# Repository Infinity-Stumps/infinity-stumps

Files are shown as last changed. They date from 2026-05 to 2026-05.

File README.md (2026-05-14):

# Infinity Stumps

**DRS for the rest of us.** Hawk-Eye-class ball tracking and LBW prediction
for cricket, at roughly 1/30th the cost — running on a consumer phone.


&nbsp;Apache-2.0 / CERN-OHL-S / CC-BY-4.0

---

Eight ultra-wideband (UWB) anchors around a cricket pitch, a tag inside the
ball, and a phone that does all the maths. It tracks the ball in 3D, predicts
trajectories, and renders DRS-style LBW verdicts — for the 99% of cricket
played in clubs, schools, academies, and back gardens that has never had
access to ball-tracking analytics.

The whole system is **open by design** — public from day one as dated,
detailed prior art so the techniques can't be locked up by anyone else.
See [`docs/about.md`](docs/about.md) for the what, why, and the open-source
posture.

## Headline results

Phase 0 simulation, n=30 deliveries at 100 Hz with a realistic occlusion
model (skeleton batter + Law-41 bowler), EKF + RTS smoother pipeline:

| Metric | Result | iBall (NSDI '17) | |
|---|--:|--:|--|
| Lateral median error at the stump line | **9.1 mm** | 99 mm | 11× better |
| 3D median error at the stump line | **28.0 mm** | 220 mm | 7.9× better |
| LBW verdict accuracy (exact match) | **96.7%** | — | 29/30 |
| False positives (wrong OUT) | **0** | — | across all 30 |

Full breakdown in [`docs/status-2026-05-13.md`](docs/status-2026-05-13.md).

## Repository layout

This is a monorepo, one directory per discipline:

| Directory | What's in it | Status |
|---|---|---|
| [`simulation/`](simulation/) | The Python estimation + LBW pipeline — physics EKF, RTS smoother, verdict logic, and the simulation harnesses that validate them. | Phase 0 complete |
| [`firmware/`](firmware/) | Anchor and ball-tag firmware for the Qorvo DWM3001C (C / nRF Connect SDK). | Not started |
| [`hardware/`](hardware/) | KiCad PCB projects and enclosure design. | Not started |
| [`app/`](app/) | The mobile app — iOS first; runs the full pipeline on-device. | Not started |
| [`docs/`](docs/) | System-level architecture, BOM, prior-art strategy, test plans. | Living |

Each directory has its own README with the detail.

## How the system works

```
  ball tag ──UWB DS-TWR @ 100 Hz──▶ 8 anchors ──▶ hub stump ──BLE──▶ phone
                                                                      │
                          per-anchor ranges ──▶ physics EKF ──────────┤
                                               + RTS smoother         │
                                               + LBW verdict          ▼
                                                          trajectory + verdict
```

- **Hardware** — 8 Qorvo DWM3001C anchors (4 stump-top, 4 ground-level), one
  designated the hub stump; a DWM3001C + impact accelerometer in the ball.
- **Estimation** — a 9-state physics EKF over (position, velocity, spin) with
  a drag + Magnus + gravity ODE, plus an RTS backward smoother for
  replay-quality precision. Runs on the phone.
- **LBW** — forward-extrapolates past the pad to the stump line, propagates the
  EKF covariance into a 95% confidence ellipse, classifies it against the
  stump rectangle as HITTING / MISSING / UMPIRE'S CALL.

## Getting started

The Phase 0 work lives in [`simulation/`](simulation/) — see its README:

```bash
cd simulation
make install
make test
python sims/sim_lbw.py
```

## Documentation

- [`docs/about.md`](docs/about.md) — what this is, the open-source posture, the prior-art strategy.
- [`docs/architecture.md`](docs/architecture.md) — full system architecture.
- [`docs/bom.md`](docs/bom.md) — active bill of materials (Qorvo DWM3001C platform).
- [`docs/prior-art.md`](docs/prior-art.md) — iBall (NSDI '17) analysis and borrowed techniques.
- [`docs/status-2026-05-13.md`](docs/status-2026-05-13.md) — current results in detail.
- [`docs/phase1-2-test-plan.md`](docs/phase1-2-test-plan.md) — hardware bring-up plan.
- `CLAUDE.md` — the running decision log. `CONTRIBUTING.md` — how to work on the project.

## Licence

Three licences by file type:

- **Software** (`simulation/`, `firmware/`, `app/`) — Apache-2.0 ([`LICENSE`](LICENSE))
- **Hardware designs** (`hardware/`) — CERN-OHL-S v2 ([`LICENSE-hardware`](LICENSE-hardware))
- **Documentation** (`docs/`, READMEs) — CC-BY-4.0 ([`LICENSE-docs`](LICENSE-docs))

## Acknowledgements

Built on **iBall** (Gowda et al., *Bringing IoT to Sports Analytics*, NSDI '17),
which established UWB ranging + physics-fit + LBW extrapolation for a cricket
ball as public prior art. This project productises that idea with modern
silicon, an 8-anchor topology, and outdoor validation.

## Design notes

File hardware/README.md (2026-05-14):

# Hardware

PCB and mechanical design for the Infinity Stumps anchors and ball tag.
Electronics built around the **Qorvo DWM3001C** module — see
`docs/bom.md` for the full bill of materials and `docs/architecture.md`
for the system design.

## Layout

| Directory | Contents |
|---|---|
| `anchor-board/` | The anchor PCB — **one design serves all eight anchor positions**. Every board is built identically (flash + load switch populated); the hub role (A7) is firmware-only and any board is hub-promotable by reflashing. Tall-and-thin to fit inside the stump. KiCad project. See its `README.md` for the full design spec. |
| `pai-board/` | The PAI (ground-level) anchor — **not an independent design**, just a one-component fork of `anchor-board/`: USB-C receptacle swapped for a magnetic charging connector, in an IP67 sealed cylinder. Same board family, same Gerbers minus the USB-C cluster. |
| `ball-tag/` | The in-ball tag — a custom 4-layer flex PCB shaped to the ball interior, carrying the DWM3001C + ADXL372 impact accelerometer + small LiPo. |
| `mechanical/` | Enclosure design — stump-top caps, PAI housings, ball shell. STL + STEP. |

Each board is its own KiCad project (schematic + layout + Gerbers).
Manufacturing outputs are committed alongside the source.

## Status

Not started. PCB design follows firmware bring-up on the DWM3001CDK
dev kits.

## Licence

CERN-OHL-S v2 — strongly reciprocal (see `LICENSE-hardware` at the repo
root). Mechanical design files (STL/STEP) are CC-BY-4.0 per the project
licensing in `docs/about.md`.

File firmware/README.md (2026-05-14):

# Firmware

Embedded firmware for the Infinity Stumps UWB nodes. All nodes are built
on the **Qorvo DWM3001C** module (DW3110 UWB transceiver + Nordic
nRF52833 BLE/MCU, with an on-module 3-axis accelerometer and 32.768 kHz
crystal).

Toolchain: **Nordic nRF Connect SDK** (Zephyr-based). The DWM3001CDK dev
kit *is* the production module, so bring-up firmware transfers directly
to production hardware.

## Layout

| Directory | Role |
|---|---|
| `anchor/` | Anchor firmware. One image with a build-time role flag — a **dumb anchor** ranges and relays; a **hub anchor** additionally acts as UWB sync master, range aggregator, BLE gateway to the phone, and disconnect-cache recorder. 7 dumb + 1 hub per pitch. |
| `ball-tag/` | Ball-tag firmware. Drives the UWB ranging exchange and reads the impact accelerometer (ADXL372) for bounce/pad/bat event timing. |
| `common/` | Shared code — UWB ranging (broadcast DS-TWR @ 100 Hz), the fixed-schedule TDMA data layer on the 802.15.4z PHY, power management, BLE service definitions. |

## Status

Not started. Phase 1+2 (hardware bring-up) begins when the DWM3001CDK
boards arrive — see `docs/phase1-2-test-plan.md` and `docs/architecture.md`.

## Licence

Apache-2.0 (see `LICENSE` at the repo root).

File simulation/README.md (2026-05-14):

# Infinity Stumps — Simulation

The Python estimation and LBW-prediction pipeline, plus the simulation
harnesses that validate it. This is the **Phase 0** work: the algorithm
architecture proven end-to-end in simulation before any hardware is built.

It is also the reference spec the firmware and the mobile app are ported
from — see the other top-level directories and the repo-root
[`README.md`](../README.md) for the whole-system picture.

## Headline results

n=30 deliveries at 100 Hz with a realistic occlusion model (skeleton
batter + Law-41 bowler), EKF + RTS smoother pipeline:

| Metric | Result | iBall (NSDI '17) | |
|---|--:|--:|--|
| Lateral median error at the stump line | **9.1 mm** | 99 mm | 11× better |
| 3D median error at the stump line | **28.0 mm** | 220 mm | 7.9× better |
| Trajectory RMS (replay) | **47.3 mm** | — | |
| LBW verdict accuracy (exact match) | **96.7%** | — | 29/30 |
| False positives (wrong OUT) | **0** | — | across all 30 |

Full breakdown in [`../docs/status-2026-05-13.md`](../docs/status-2026-05-13.md).

## The pipeline

- **Physics EKF** — a 9-state Extended Kalman Filter over (position, velocity,
  spin), propagated with a drag + Magnus + gravity ODE and updated per UWB
  range measurement. Runs forward in real time for a live overlay.
- **RTS smoother** — a Rauch–Tung–Striebel backward pass that retrofits past
  estimates with later measurements for replay-quality precision.
- **LBW pipeline** — forward-extrapolates the ball past the pad to the stump
  line, propagates the EKF covariance into a 95% confidence ellipse, and
  classifies it against the stump rectangle as HITTING / MISSING / UMPIRE'S CALL.

## Layout

| Path | What's in it |
|---|---|
| `src/infinity_stumps/geometry.py` | Pitch geometry, anchor layouts, GDOP. |
| `src/infinity_stumps/physics.py` | Ball flight dynamics (drag + Magnus + gravity, bounce). |
| `src/infinity_stumps/solver.py` | Multilateration and physics-constrained trajectory fit. |
| `src/infinity_stumps/ekf.py` | The production estimator: trajectory EKF + RTS smoother. |
| `src/infinity_stumps/lbw.py` | LBW extrapolation, uncertainty ellipse, verdict logic. |
| `src/infinity_stumps/noise.py` | UWB ranging noise models (Gaussian + occlusion/NLOS). |
| `src/infinity_stumps/skeleton.py` | Anthropometric skeleton batter for the occlusion model. |
| `sims/` | Standalone simulation scripts — each writes a PNG to `outputs/`. |
| `tests/` | Per-module test suite (`pytest`). |
| `outputs/` | Committed simulation result figures. |

## Quickstart

Requires Python 3.10+. Run everything from this directory.

```bash
make install      # editable install with dev extras + pre-commit hooks
make test         # run the test suite
make check        # the full gate: lint + typecheck + test
make sims         # regenerate every figure in outputs/
```

`make help` lists every target. Without `make`:

```bash
pip install -e ".[dev]"
pytest
python sims/sim_lbw.py
```

## Simulations

Each script in `sims/` is self-contained and writes a figure to `outputs/`.

| Script | What it shows |
|---|---|
| `sim_ekf.py` | **EKF + RTS smoother** — the production estimator (current primary). |
| `sim_lbw.py` | **LBW prediction + verdict** — 96.7% exact-match accuracy. |
| `sim_realistic.py` | Batch-fit baseline under realistic occlusion (deprecated primary). |
| `sim_ml.py` | ML correction-layer exploration (concluded net-neutral). |
| `01_precision_map.py` | GDOP map across the pitch. |
| `02_anchor_comparison.py` | 8 vs 12 anchors (12 rejected — <2% gain). |
| `03_trajectory_recovery.py` | Clean-LOS physics fit. |
| `05_multipath_occlusion.py` | NLOS impact, no mitigations (the problem). |
| `05b_occlusion_mitigations.py` | Huber loss + NLOS detection (the fix). |
| `06_imu_fusion.py` | Complementary-filter IMU fusion (rejected — see `../docs/findings.md`). |
| `07_sync_budget.py` | TDoA noise floor (why the system uses TWR, not TDoA). |
| `11_ground_multipath.py` | Outdoor ground-reflection multipath. |

## Contributing

See [`../CONTRIBUTING.md`](../CONTRIBUTING.md). In short: `make check` must
pass, and the project values dated decisions and explicit reasoning.

## Licence

Apache-2.0 (see [`../LICENSE`](../LICENSE)).

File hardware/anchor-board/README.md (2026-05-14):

# Anchor Board

The stump-anchor PCB for Infinity Stumps. **One board design serves all
eight anchor positions** — the four stump-top anchors (A1, A2, A7, A8)
and, with only an enclosure + charge-connector change, the four in-ground
PAI anchors (A3–A6). The hub role (A7) is **firmware-only**: the same
fully-populated board, reflashed.

This document is the design specification — form factor, functional
blocks, the complete passive component list, pin allocation, layout
rules, and the dev-board → production-board conversion plan. It should be
read alongside `docs/bom.md` (costed BOM) and `docs/architecture.md`
(system design). KiCad project lives in this directory once started.

**Status:** specification. No schematic/layout yet.

---

## 1. Design philosophy: one board, dev first, production by subtraction

The board is designed as a **development board that converts into the
production board by subtraction only** — no re-layout, no re-spin.

This is cheap to do here because the **DWM3001C is a pre-certified
module**, not a bare chip: the nRF52833 MCU, the DW3110 UWB radio, the
UWB + BLE antennas, the 32.768 kHz LFXO crystal and a low-g accelerometer
are all *inside* the module. The board we are designing is therefore a
**carrier** — power, charging, storage, status I/O, and breakouts. There
is almost no RF layout risk (just a keepout under the module antenna), so
"dev = production + extra parts" is genuinely achievable.

**Mechanism:**

- **Single 4-layer PCB, single set of Gerbers, two assembly BOMs.**
- The production circuit lives in the board core.
- All dev-only conveniences (full SWD header, UART header, GPIO breakout,
  current-measurement shunt, LED-disable jumper) sit on a **V-scored
  break-off rail** along one long edge.
- For production: snap off the rail and mark the dev-only parts DNP. Same
  fab output, different pick-and-place file.

See §8 for the full conversion checklist.

### Hub vs dumb: populate flash on every board

**This design populates the 16 MB flash + load switch on every board.**
The cost is ~£1.20/board (~£8/pitch — noise against the ~£601 pitch
cost), and in return there is a **single assembly BOM** and **any board
is promotable to hub by reflashing**. No second variant to stock, build,
or track. The hub/dumb distinction is entirely firmware. `docs/bom.md`
is written to match — there is no separate hub SKU.

---

## 2. Form factor — tall and thin, fits inside the stump

The board drops vertically down inside a hollow cricket stump (≈38 mm
outer diameter, ≈30–34 mm internal bore). It occupies only the **upper
~145 mm** of the stump.

**Nominal envelope: 25 mm wide × ≈145 mm long, 4-layer, 1.6 mm.**

Width is set by the DWM3001C (19.13 mm wide) plus a ~3 mm routing rail
each side. Length is a vertical stack of functional zones:

```
   ┌─────────────┐  ← TOP of stump (z = 680 mm anchor reference point)
   │  ANTENNA    │  ~6 mm   Module sits fully on-board; this zone is an
   │  (keepout)  │          all-layer copper keepout under the DWM3001C
   │             │          antenna, per the Qorvo integration guide.
   ├─────────────┤
   │  DWM3001C   │  ~21 mm  Module body. Castellation pads both long
   │   MODULE    │          edges. Decoupling on the back side.
   ├─────────────┤
   │  POWER &    │  ~30 mm  LDO, charger, battery protection, SPI flash,
   │  SUPPORT    │          load switch, ESD array, RGB LED, button.
   ├─────────────┤
   │             │
   │   18650     │  ~77 mm  Keystone 1042 single-cell holder, PC-pin
   │   HOLDER    │          mount. Battery sits on top of the PCB; this
   │             │          zone carries no other components.
   │             │
   ├─────────────┤
   │  USB-C +    │  ~12 mm  USB-C receptacle on the long edge, port
   │  CHG INPUT  │          facing OUT the side of the stump.
   └─────────────┘  ← ≈145 mm below stump top — still ≈350 mm+ above
                      ground, so the side charge slot stays clear of
                      the buried portion of the stump.
═══ V-score ═══════  Break-off dev rail runs the full length on one
   [ dev rail   ]    long edge (see §7).
```

**Cross-section inside the stump:** PCB (25 mm × 1.6 mm) with the 18650
(≈18 mm dia) lying on top → ≈25 mm wide × ≈20 mm tall. Comfortably
inside a ≈30–34 mm bore. The 18650 holder must be retained against the
PCB with the BOM's cell clip — the board will see knocks and the ball's
impact shock through the stump.

**Orientation is fixed:** antenna end UP (it is the anchor's z = 680 mm
reference point), USB-C end DOWN. The PAI variant has no "up" constraint
and swaps the USB-C zone for a 2-pin magnetic charge connector.

---

## 3. Functional block diagram

```
                 USB-C VBUS ─► [TPD4S014] ─► [BQ24074] ─► VSYS ──┬──► [TLV75530] ──► 3V0 rail
                 (5 V in)       ESD/TVS       Li-ion charger      │     LDO            │
                                                  │              │                   ├─► DWM3001C  (2.5–3.6 V)
                 USB-C CC1/CC2 ─► 5k1 Rd ─► GND   │              │                   ├─► W25Q128 flash
                                                  ▼              │                   │   (via TPS22916 switch)
                                       [18650 cell] ◄─► [DW01A    │                   ├─► RGB LED
                                        3400 mAh        + 8205A]  │                   └─► (button pull-up)
                                                        protection│
                                                                  │
                          VBAT sense divider ──────────────────────┘──► nRF52833 ADC

   DWM3001C (module): nRF52833 MCU + DW3110 UWB + on-module antennas,
                      32.768 kHz LFXO, low-g accel — all internal.
        GPIO ─► SPI to W25Q128   │   GPIO ─► TPS22916 ON   │   GPIO ─► RGB LED ×3
        GPIO ◄─ power button     │   ADC  ◄─ VBAT sense    │   GPIO ◄─ BQ24074 /CHG, /PGOOD
        SWD / UART / spare GPIO ─► break-off dev rail
```

---

## 4. Functional blocks and their passives

This is the **complete passive list**, grouped by block. Values are the
design intent; finalise against each IC's datasheet app circuit during
schematic capture. Reference designators are indicative.

### 4.1 DWM3001C module

The module needs almost nothing external — its job is done internally.

| Ref | Part | Value | Purpose |
|---|---|---|---|
| C1, C2 | Capacitor 0402 | 100 nF | VDD pin decoupling, one per supply pin group, placed hard against the castellations |
| C3 | Capacitor 0805 | 10 µF | Bulk decoupling on the module 3V0 feed |
| R1 | Resistor 0402 | 10 kΩ | nRESET pull-up |
| C4 | Capacitor 0402 | 100 nF | nRESET RC debounce (to GND) |

Antenna region: **copper keepout on all layers** under and around the
module's antenna end, per the Qorvo DWM3001C integration guidelines. No
ground pour, no traces, no vias. The module sits **fully on the board**
(no overhang) — the keepout gives the RF clearance, and keeping the
module fully supported is the mechanically robust choice inside the cap,
where the board takes ball-impact shock through the stump.

### 4.2 USB-C input + ESD (production: stump anchors only)

Sink-only, no USB-PD, no data — power in at 5 V.

| Ref | Part | Value | Purpose |
|---|---|---|---|
| J1 | GCT USB4105-GF-A | — | USB-C receptacle, long-edge mount, port facing out |
| R2, R3 | Resistor 0402 | 5.1 kΩ | CC1 / CC2 pull-downs (Rd) — required for a source to detect the sink |
| C5 | Capacitor 0805 | 10 µF | VBUS bulk cap |
| C6 | Capacitor 0402 | 100 nF | VBUS HF decoupling |
| U2 | TI TPD2E2U06 | — | 2-channel low-cap (1.5 pF) TVS ESD array on the CC1 / CC2 lines |
| D2 | TVS diode, SMF5.0A class | — | VBUS ESD / surge clamp (~5 V standoff), VBUS → GND |
| R4 | Resistor 0402 | 1 MΩ | Shield-to-GND bleed (parallel with C7) |
| C7 | Capacitor 0402 | 4.7 nF | Shield-to-GND, chassis noise return |

> **ESD parts — changed from the original spec.** The first draft listed
> a single TI TPD4S014, but that is a USB *data-port* protector
> (D+/D−/ID clamps + a VBUS load switch) — wasted on this sink-only,
> power-only port. Replaced with the **TPD2E2U06** (TI's CC-line ESD
> array) plus a dedicated **VBUS TVS diode (D2)**.

> **PAI variant:** J1, R2, R3 and U2 are replaced by a 2-pin magnetic
> charge connector (Rosenberger) — the magnetic connector has no CC
> lines, so the CC pull-downs and the CC ESD array are not fitted. D2
> (VBUS TVS) stays; the magnetic connector still feeds VBUS. This is the
> only electrical difference between the stump and PAI boards.

### 4.3 Li-ion charger — TI BQ24074

| Ref | Part | Value | Purpose |
|---|---|---|---|
| U3 | TI BQ24074 | — | USB-input Li-ion CC/CV charger |
| C8 | Capacitor 0603 | 1 µF | IN pin input cap |
| C9 | Capacitor 0603 | 1 µF | OUT pin cap |
| C10 | Capacitor 0603 | 1 µF | BAT pin cap |
| R5 | Resistor 0402 | 909 Ω | ISET — fast-charge current ≈ 1.0 A (≈0.3C on a 3400 mAh cell; conservative for outdoor temps) |
| R6 | Resistor 0402 | TBD | TMR — safety-timer program resistor, sized for a ~10 h timer (generous margin over a ~0.3C charge); value from the BQ24074 datasheet timer equation at schematic capture |
| R7, R8 | Resistor 0402 | 10 kΩ + 10 kΩ | TS pin — equal divider holds TS at mid-rail, disabling temperature sensing in v1 (no pack thermistor). v2 may swap R8 for an NTC. |
| R9, R10 | Resistor 0402 | 10 kΩ | /CHG and /PGOOD open-drain pull-ups to 3V0, also sensed by MCU GPIO |
| R11, R12 | Resistor 0402 | strap | EN1 / EN2 mode straps — set input current limit (USB500 / ISET) |
| R24 | Resistor 0402 | TBD | ILIM — input-current-limit program resistor; value from the BQ24074 datasheet at schematic capture |
| R25 | Resistor 0402 | TBD | ITERM — charge-termination-current program resistor; value from the BQ24074 datasheet at schematic capture |

> **R24 / R25 added during schematic capture.** The BQ24074's ILIM
> (input current limit) and ITERM (termination current) pins each need a
> program resistor; the original §4.3 list omitted them. The refs
> continue past the §4 sequence (R15–R23 belong to §4.6–4.8).

### 4.4 Battery + protection — 18650 + DW01A/8205A

| Ref | Part | Value | Purpose |
|---|---|---|---|
| BT1 | Panasonic NCR18650B | 3400 mAh | Single Li-ion cell, in Keystone 1042 holder |
| U4 | DW01A | — | Protection controller (over-charge / over-discharge / over-current) |
| U5 | 8205A | — | Dual N-FET, protection switch (no passives of its own) |
| R13 | Resistor 0402 | 330 Ω | DW01A VCC series resistor |
| C11 | Capacitor 0402 | 100 nF | DW01A VCC–VSS decoupling |
| R14 | Resistor 0402 | 2 kΩ | DW01A current-sense input resistor |

### 4.5 3.0 V regulation — TI TLV75530

| Ref | Part | Value | Purpose |
|---|---|---|---|
| U6 | TI TLV75530PDQNR | 3.0 V | Low-IQ 500 mA LDO, battery → 3V0 system rail |
| C12 | Capacitor 0603 | 1 µF | VIN cap |
| C13 | Capacitor 0603 | 1 µF | VOUT cap |
| C14 | Capacitor 0805 | 10 µF | 3V0 rail bulk cap |
| FB1 | Ferrite bead 0603 | — | Optional: charger-OUT → LDO-IN, isolates charge ripple from the rail |

### 4.6 SPI flash + load switch — W25Q128 + TPS22916C

Populated on **every** board (see §1).

| Ref | Part | Value | Purpose |
|---|---|---|---|
| U7 | Winbond W25Q128JVSIQ | 16 MB | Disconnect-cache flash (hub firmware uses it; dumb firmware leaves it idle) |
| U8 | TI TPS22916C | — | Load switch — gates flash VCC in deep sleep (~1 µA saving) |
| C15 | Capacitor 0402 | 100 nF | W25Q128 VCC decoupling |
| C16 | Capacitor 0603 | 1 µF | TPS22916 output cap |
| R15 | Resistor 0402 | 10 kΩ | /CS pull-up (idle-high during MCU boot) |
| R16, R17 | Resistor 0402 | 10 kΩ | /WP and /HOLD pull-ups (single-SPI mode, tied inactive) |

> **C17 removed during schematic capture.** The original list specced a
> "TPS22916 CT" slew-rate cap, but the TPS22916 (4-pin WCSP — VIN / VOUT
> / GND / ON) has **no CT pin**; turn-on slew rate is fixed by the part
> variant (the "C" suffix = slow timing), not an external cap.

### 4.7 User I/O — RGB LED + power button

| Ref | Part | Value | Purpose |
|---|---|---|---|
| D1 | Würth 150141RV73100 | — | Common-anode RGB status LED, 0805 |
| R18 | Resistor 0402 | 1 kΩ | Red current limit (run dim — LED is a battery drain) |
| R19 | Resistor 0402 | 680 Ω | Green current limit |
| R20 | Resistor 0402 | 680 Ω | Blue current limit |
| SW1 | Alps SKHHALA010 | — | Side-mounted IP67 tactile power/mode button |
| R21 | Resistor 0402 | 10 kΩ | Button pull-up (or use nRF internal pull and DNP) |
| C18 | Capacitor 0402 | 100 nF | Button debounce |

> **Power-button behaviour: soft-wake, no hard latch.** The button is an
> MCU GPIO wake/mode source; "off" is nRF52833 deep sleep (System OFF
> ≈ a few µA; the power budget's conservative ~50 µA sleep figure
> already covers this). No load-switch latch on the 3V0 rail. Rationale:
> the anchor must always be able to wake on UWB, BLE or motion — a hard
> "dead until button" state breaks the hub-as-recorder behaviour and the
> 290-day runtime is already computed against deep sleep, not a true
> zero-draw off. Fewer parts, more robust.

### 4.8 Battery voltage sense

Needed for the `battery_pct` field in the hub's BLE Status characteristic.

| Ref | Part | Value | Purpose |
|---|---|---|---|
| R22, R23 | Resistor 0402 | 1 MΩ + 1 MΩ | High-impedance divider, VBAT → nRF ADC pin (≈2 µA drain — acceptable vs 50 µA sleep) |
| C19 | Capacitor 0402 | 100 nF | ADC anti-alias / sample-and-hold filter |

### 4.9 Rail-level / misc

| Ref | Part | Value | Purpose |
|---|---|---|---|
| TP1–TP6 | Test points | — | VBUS, VSYS, VBAT, 3V0, GND ×2 — keep on the production board, they cost nothing |
| C20 | Capacitor 0805 | 10 µF | Extra 3V0 bulk near the module if layout needs it |

**Passive count, production board:** ≈40 parts — caps, resistors, one
ferrite. All 0402/0603/0805, single reel-friendly family. This maps to
the BOM's "Bulk decoupling caps ×4 / Misc passives" lines, which should
be expanded to match this list (see §10).

---

## 5. Pin allocation (reconciled against the datasheet)

Finalised against the DWM3001C datasheet castellation map (Data Sheet
Rev F, §3). The schematic symbol and netlist now use the **real pin
numbers**; `tools/gen_dwm3001c_symbol.py` is the source of this table.

| Function | Module pin | nRF GPIO | Notes |
|---|---:|---|---|
| VDD | 12 | — | 3.0 V supply from the LDO |
| GND | 1, 11, 21, 38, 48 | — | All five module grounds tied to GND |
| nRESET | 47 | P0.18 | R1 pull-up; TC2030 pads + dev-rail header |
| SWDCLK | 2 | — | Dedicated SWD; TC2030 pads + dev-rail header |
| SWDIO | 3 | — | Dedicated SWD; TC2030 pads + dev-rail header |
| UART_TX | 27 | P1.09 | nRF log console → dev-rail header only |
| UART_RX | 28 | P1.00 | nRF log console → dev-rail header only |
| BTN | 13 | P0.12 | Power/mode button, wake source |
| CHG_STAT | 17 | P0.20 | BQ24074 /CHG (open-drain) |
| PGOOD | 16 | P0.21 | BQ24074 /PGOOD (open-drain) |
| VBAT_SENSE | 42 | P0.31 | SAADC AIN7 — via R22/R23 divider |
| SPI_SCK | 22 | P0.11 | W25Q128 flash |
| SPI_MOSI | 23 | P1.08 | W25Q128 flash |
| SPI_MISO | 24 | P0.06 | W25Q128 flash |
| SPI_CS | 25 | P1.01 | W25Q128 flash |
| FLASH_EN | 26 | P0.13 | TPS22916 ON pin |
| LED_R / LED_G / LED_B | 6 / 7 / 8 | P0.17 / P0.14 / P0.22 | RGB LED, common-anode (drive low = on) |
| GPIO1–4 | 29 / 32 / 33 / 34 | P1.05 / P0.15 / P0.28 / P0.19 | Spare, broken out to the dev rail |

Pins **4, 5** (P0.09/P0.10) default to NFC and are left unconnected.
Pins **14, 15** (P0.24/P1.04) are the **on-module accelerometer I²C** —
left unconnected so the carrier never drives them. The remaining
castellations (USB_N/P, the DW3110 GPIOs, spare P0.x) are typed
`no_connect` in the symbol — those pads float on this board by design.
There is no EN1/EN2 GPIO: the BQ24074 mode is hard-strapped (R11/R12),
which was always the plan — the earlier "EN1/EN2" pins were a
placeholder-symbol artefact, now gone.

The DW3110 UWB radio talks to the nRF52833 over an **on-module** SPI bus
— not exposed, not our concern.

---

## 6. Layer stack-up and layout rules

**4-layer, 1.6 mm:** `Signal / GND / PWR / Signal`.

1. **Antenna keepout** — the single hard RF rule. All-layer copper
   keepout under/around the DWM3001C antenna end, per Qorvo's
   integration guide. No pour, no trace, no via, no battery, no metal
   nearby. This protects the module's pre-certification.
2. **Module placement** — DWM3001C at the top edge, antenna outboard.
   Decoupling caps (C1–C3) on the *back* side directly behind the supply
   castellations.
3. **USB-C** — keep VBUS traces short and wide; TPD4S014 placed right at
   the connector, before anything else. CC pull-downs at the connector.
4. **Charge/power path** — BQ24074 → DW01A/8205A → TLV75530 in a compact
   cluster in the Power & Support zone. Keep the high-current battery
   loop (cell → 8205A → charger/load) tight; star-ground the analog
   return of the VBAT divider away from it.
5. **18650 zone** — no components, but route the cell + / − traces
   wide (charge current up to 1 A). The holder's PC pins anchor it
   mechanically; pair with the BOM cell clip.
6. **Thermal** — negligible. Worst case ≈8 mA average, ≈1 A only while
   charging; modest copper pour on the PWR layer around the charger is
   plenty. No concern in a sealed stump.
7. **Mechanical** — M2 mounting holes (BOM standoffs) at the corners of
   the rigid core; keep them out of the antenna keepout. The board takes
   ball-impact shock transmitted through the stump — no tall unsupported
   parts, secure the cell.

---

## 7. The break-off dev rail

A V-scored strip down one long edge, snapped off for production. Carries
**only** bring-up and validation aids:

| Dev-rail item | Why it is dev-only |
|---|---|
| 2×5 1.27 mm SWD/JTAG header | Production uses the Tag-Connect pads on the core board; the shrouded header is faster for daily flashing/debug |
| UART header (TX/RX/GND) | nRF RTT/console logging during bring-up |
| GPIO breakout (spare ×4–6 + I²C/SPI taps) | Probing, logic analyser, attaching test sensors |
| **3V0 current-shunt jumper** | A 2-pin header in series with the 3V0 rail. Pull the jumper, insert a µA meter — **this is how the 290-day / ~50 µA sleep budget gets validated.** Production: replace with a 0 Ω. |
| LED-disable jumper | LEDs wreck a sleep-current measurement; cut them cleanly during power profiling |
| Boot/mode strap pads | Recovery / forced-DFU during firmware bring-up |

The core board is **fully functional with the rail removed** — the
Tag-Connect pads, the 0 Ω in place of the shunt jumper, and the on-board
RGB LED cover everything production needs.

---

## 8. Dev → production conversion checklist

No re-layout. No re-spin. Same Gerbers. To go from dev to production:

1. **Snap off** the V-scored dev rail.
2. **Fit R_shunt = 0 Ω** in the current-shunt jumper position.
3. **Mark DNP:** dev-rail parts (already gone with the rail), the SWD
   shrouded header, UART header, GPIO breakout, mode-strap pads.
4. **Stuff the Tag-Connect TC2030 pads** (they are on the core board, not
   the rail).
5. Swap the **assembly/pick-and-place BOM** to the production variant.
   Fab output (Gerbers, drill, netlist) is **identical**.
6. PAI-board fork only: swap the USB-C cluster (J1/R2/R3) for the
   magnetic connector footprint — a one-component schematic change, same
   board family.

---

## 9. Decisions made and remaining open items

**Resolved in this design:**

- **Form factor** — ≈25×145 mm, tall-and-thin (§2). `docs/bom.md` updated
  to match (PCB line, cost).
- **Flash on every board** — single assembly BOM, any board
  hub-promotable (§1). `docs/bom.md` and `docs/architecture.md` updated.
- **Power button** — soft-wake, no hard latch (§4.7).
- **Antenna** — module fully on-board with an all-layer keepout, no
  overhang (§4.1).
- **BQ24074 TS** — temperature sensing disabled with a fixed 10k/10k
  divider in v1, no pack thermistor (§4.3).

**Still open (need the mechanical/enclosure design or a datasheet pass):**

- **18650 holder exact footprint.** The ~77 mm zone is sized for the
  Keystone 1042; confirm the real footprint (PC-pin pitch, retention)
  before fixing the final board length.
- **USB-C side-slot sealing.** Design assumes a side slot in the stump
  wall ≈145 mm below the top, IP54-gasketed. Mechanical design to
  confirm the slot seals acceptably vs. the alternative of routing the
  port through the stump-top cap (rejected here — it crowds the antenna
  and the cap is the removable part).
- **BQ24074 TMR resistor value** — set from the datasheet timer equation
  at schematic capture (target ~10 h safety timer).

## 10. BOM reconciliation — done

`docs/bom.md` and `docs/architecture.md` have been updated to match this
design (2026-05-14):

- **PCB size** 30×40 mm → ≈25×145 mm, £2.00 → £3.50.
- **Flash + load switch** moved from a hub-only extra into the base
  stump-anchor BOM (populated on every board); the separate hub SKU is
  gone — hub is firmware-only.
- **Passives** — the "bulk caps ×4" + "misc passives" lines collapsed
  into one "Passives (~40 parts)" line referencing §4 here, £0.70 →
  £0.80. This now covers the VBAT sense divider (§4.8) and USB shield RC
  (§4.2).
- Per-pitch electronics £262 → £281; per-pitch total £582 → £601.

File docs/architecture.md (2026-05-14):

# Infinity Stumps — Technical Architecture

> System architecture for the Infinity Stumps ball tracking + LBW prediction
> system. Reference document for v1.

**Version:** v1 (May 2026)
**Status:** Simulation-validated. Hardware bring-up in progress.
**Last updated:** 2026-05-13

---

## 1. System Overview

### 1.1 Goal

Track a regulation cricket ball in 3D through delivery, flight, bounce,
and post-bounce with Hawk-Eye-class precision, and provide a DRS-style
LBW prediction with an uncertainty ellipse. All processing runs on a
consumer smartphone connected to a small fixed-position UWB sensor
network at the pitch.

### 1.2 Scope

**In scope (v1):**
- Single-pitch installation (8 anchors + ball tag)
- Ball trajectory tracking + 3D physics fit
- LBW prediction with HIT / MISS / UMPIRE'S CALL verdict
- DRS replay overlay on iPhone / iPad
- Live broadcast overlay (best-effort)

**Out of scope (v1):**
- Spin analytics (v2 — magnetometer-based)
- No-ball detection, run-out review, multi-camera reconstruction
- Edge / sound detection
- Multi-pitch / venue-wide tracking
- Player tracking (UWB sensors on players)
- Cloud sync, multi-device session sharing

### 1.3 Key performance claims (sim, n=30)

| Metric | Value | Source |
|---|---:|---|
| Trajectory 3D RMS mean | 47 mm | sim_ekf |
| Trajectory 3D RMS p95 | 61 mm | sim_ekf |
| LBW lateral error median | 9 mm | sim_lbw |
| LBW 3D error median | 28 mm | sim_lbw |
| LBW verdict accuracy | 96.7% | sim_lbw, n=30 |
| LBW false-positive rate | 0% | sim_lbw, n=30 |
| Cost target | ~£1,500 per pitch | BOM in §3 |

### 1.4 Comparison to existing systems

| System | Precision | Cost | Form factor | Target |
|---|---|---|---|---|
| Hawk-Eye | ~30 mm (field) | £100K–£250K + £20-50K/yr | Trucks, masts, multiple HD cameras | International cricket |
| iBall (NSDI '17) | 80 mm median (indoor) | research prototype, never productised | 2 anchors + ball-embedded UWB | Research |
| **Infinity Stumps v1** | **47 mm mean** | **~£1,500** | **8 small anchors + ball + phone** | **Clubs, schools, coaches** |

---

## 2. Conceptual Architecture

### 2.1 System block diagram

```
                                  ┌─────────────────────────┐
                                  │   iPhone / iPad         │
                                  │   ───────────────────   │
                                  │   • EKF + RTS smoother  │
                                  │   • LBW verdict + UI    │
                                  │   • Swift + Accelerate  │
                                  │   • CoreML (v2+)        │
                                  └────────────▲────────────┘
                                               │ BLE
                                               │ (single peripheral link)
                                  ┌────────────┴────────────┐
                                  │   HUB STUMP (Anchor A7) │
                                  │   ───────────────────   │
                                  │   • UWB sync master     │
                                  │   • Range aggregator    │
                                  │   • Flash ring buffer   │
                                  │   • BLE gateway         │
                                  └────────────▲────────────┘
                                               │
                          ┌────────────────────┴────────────────────┐
                          │   UWB data-mode packets (6.5 GHz)       │
                          │   Sync + ranging + telemetry            │
                          ├────────┬────────┬────────┬──────┬───────┤
                          ▼        ▼        ▼        ▼      ▼       ▼
                       ┌────┐  ┌────┐  ┌────┐  ┌────┐  ┌────┐  ┌────┐
                       │ A1 │  │ A2 │  │ A3 │  │ A4 │  │ A5 │  │ A6 │  ... A8
                       └────┘  └────┘  └────┘  └────┘  └────┘  └────┘
                       Dumb peer anchors (same chip, simpler firmware)
                                               │
                                               │ UWB DS-TWR @ 100 Hz
                                               ▼
                                  ┌─────────────────────────┐
                                  │   BALL TAG              │
                                  │   ───────────────────   │
                                  │   • DWM3001C (UWB+BLE)  │
                                  │   • ADXL372 (impact)    │
                                  │   • Battery + antenna   │
                                  └─────────────────────────┘
```

### 2.2 Three computational layers

The system has three concurrent compute layers, each owning a
different time-scale:

| Layer | Hardware | Rate | Owns |
|---|---|---:|---|
| **Ranging** | Anchors + ball | 100 Hz | TWR exchanges, NLOS chip-level detection |
| **Aggregation** | Hub stump | 100 Hz | Sync, range collation, BLE forwarding |
| **Inference** | iPhone | per-cycle + RTS pass | EKF state, LBW verdict, UI |

Each layer is isolated from the others' timing constraints — the
anchors don't care about the iPhone's compute load, and the iPhone
doesn't need to keep up with anchor scheduling.

---

## 3. Hardware Architecture

### 3.1 Bill of materials (per pitch)

| Item | Qty | Unit cost | Notes |
|---|---:|---:|---|
| Stump anchor | 4 | ~£31 | DWM3001C + 1× 18650 + 16 MB flash + USB-C. **Identical hardware** A1/A2/A7/A8; A7 runs hub firmware |
| PAI ground anchor | 4 | ~£39 | Same board, magnetic connector instead of USB-C + IP67 sealed cylinder |
| Ball tag | N | ~£53 | DWM3001C + ADXL372 + small LiPo + impact-survival shell |
| **Per-pitch subtotal** | | **~£281** | Plus N balls. No edge PC. See `bom.md` for the line-item breakdown. |

One board design serves all eight anchor positions — the hub (A7) is
firmware-only, and the PAI variant is a one-component connector fork.
See `hardware/anchor-board/README.md`.

Enclosure / assembly costs roughly double the silicon, so realistic
fully-assembled per-pitch cost ≈ **£700-£1,200** depending on volume.

**Battery lifecycle:** 1× 18650 at ~3500 mAh gives ~290 days of active
use per the power budget in §3.5 — a full cricket season. Recharge in
the off-season. ~10-year service life with annual deep cycles.

### 3.2 Anchor placement (Laws of Cricket compliant)

| ID | Position | Z (mm) | Mount | Role |
|---|---|---:|---|---|
| A1 | Bowler off stump | 680 | Top of stump | Dumb peer |
| A2 | Bowler leg stump | 680 | Top of stump | Dumb peer |
| A3 | Bowler off-side PAI | 0 | Flush in-ground | Dumb peer |
| A4 | Bowler leg-side PAI | 0 | Flush in-ground | Dumb peer |
| A5 | Batter off-side PAI | 0 | Flush in-ground | Dumb peer |
| A6 | Batter leg-side PAI | 0 | Flush in-ground | Dumb peer |
| **A7** | **Batter off stump** | **680** | **Top of stump** | **Hub stump** |
| A8 | Batter leg stump | 680 | Top of stump | Dumb peer |

Constants in `simulation/src/infinity_stumps/geometry.py`:
- `PITCH_HL = 10.06 m` (half pitch length, ICC standard 22 yards)
- `PAI_X = 7.62 m` (Protected Area Indicator longitudinal offset)
- `PAI_Y = 1.53 m` (PAI lateral offset)
- `STUMP_W = 0.2286 m` (9 inches, ICC standard)
- `STUMP_TOP = 0.680 m` (top of stump, just below bail)
- `STUMP_HEIGHT = 0.711 m` (full ICC stump height)

### 3.3 Anchor electronics

All 8 anchors use the same hardware platform — only firmware differs:

**Qorvo DWM3001C module** (27 × 19.13 × 3.2 mm):
- DW3110 UWB transceiver (channels 5/9, FiRa-compliant DS-TWR)
- Nordic nRF52833 SoC (Cortex-M4F @ 64 MHz, BLE 5, 802.15.4)
- Integrated 3-axis accelerometer (motion-wake, ball-strike,
  knockover detection — no separate accel IC needed)
- Integrated UWB antenna + 2.4 GHz antenna
- On-module 32.768 kHz LFXO crystal (RTC / BLE timing reference)
- Pre-certified (FCC / ISED / CE / UKCA), Nordic nRF Connect SDK
  (Zephyr-based)

**Why DWM3001C** (chosen over Qorvo QPK3000, May 2026):
- The DWM3001CDK dev kit *is* the production module — bring-up
  firmware transfers directly to production hardware.
- Available from stock (QPK3000 had 12-16 week constrained lead times).
- Integrated accelerometer + on-module 32 kHz crystal → fewer BOM
  line items.
- nRF52833 → Nordic nRF Connect SDK, the best-supported UWB+BLE
  toolchain.
- Mature, widely-deployed DW3110 + nRF52833 combination.

**Standards posture:**
- For ranging: **FiRa-compliant** secure DS-TWR.
- For data exchange (peer → hub): a **thin, fixed-schedule TDMA data
  layer** on the 802.15.4z PHY, synchronised by the hub's cycle-start
  beacon. Not a general-purpose MAC — a static per-anchor slot
  schedule, which is all the disconnect-cache data model (§5.4)
  requires. ~1-2 weeks firmware.
- Marketing wording: "FiRa-compliant ranging plus proprietary
  fixed-schedule data frames on the 802.15.4z PHY." Accurate, honest.
  Do not claim "FiRa-compliant data exchange" — not a thing in the
  standard.

**Per-anchor additions:**
- 1× 18650 Li-ion (~3500 mAh, ~290 days runtime at 12 mAh/day average)
- (The 32.768 kHz LFXO crystal is on the DWM3001C module — no
  separate part. It provides the stable BLE timing / RTC reference
  during sleep that the internal RC oscillator can't.)
- USB-C for charging + firmware updates (PAI anchors: magnetic
  connector instead, to maintain IP67)
- Custom enclosure (stump-top or sealed in-ground)
- 16 MB SPI flash (Winbond W25Q128) + load switch — **populated on
  every board** but used only by the hub firmware as a **disconnect
  cache** (not a queryable archive). Phone is the source of truth; the
  hub forwards cycles via BLE notifications and writes a backup copy to
  flash with a monotonic sequence counter. On reconnect after a BLE
  drop, the phone requests gap-fill by sequence range. 16 MB at our
  throughput is comfortably more than a whole-session-disconnect's
  worth of cache. Fitting the flash on every board (vs hub-only) costs
  ~£1.20/board, keeps a single assembly BOM, and makes any anchor
  hub-promotable by reflashing. See §5 for the protocol.

### 3.4 Ball tag electronics

| Component | Function | Notes |
|---|---|---|
| DWM3001C | UWB ranging + BLE telemetry | Same module as anchors |
| ADXL372 (±200g) | Impact event timing | Saturates on amplitude but timestamp is fine |
| LiPo battery | ~75 min runtime | Power-optimised, sleep between sessions |
| Custom shell | Cricket-ball form factor | Phase 4a — 3D printed initially |

**Not in v1 ball:**
- Precision IMU (gyro saturates at cricket spin; sim 06 failure)
- Magnetometer (v2 — spin analytics)
- Piezo high-g sensor (sim showed net-neutral for our pipeline)

---

## 4. Coordinate System

```
                                  ^ +Z (up)
                                  |
                                  |
        bowler end                |              batter end
                                  |
   A1, A2   A3, A4                |               A5, A6   A7, A8
    │         │                   |                │         │
    │         │       o←──── ball ───→ o           │         │
    │         │                   |                │         │
    └─── x = -10.06 m ────────────┼────────────── x = +10.06 m ──┘
                                  |
                                  └─→ +X (along pitch, batter end positive)
```

**Origin:** centre of pitch (centre of both popping crease lines'
midpoint), at ground level.

**Axes:**
- X — along pitch, positive toward batter end
- Y — across pitch, positive toward leg side (right-hand batter)
- Z — vertical, positive up

**Right-handed coordinate system.**

**Convention notes:**
- Bowler stumps at x = -10.06 m
- Batter stumps at x = +10.06 m
- Stump centres at y = ±0.114 m (off and leg)
- PAIs at (x = ±7.62, y = ±1.53)
- Ball spin axis components: same coord system

---

### 3.5 Power budget (per anchor)

Annualised use pattern: matches and training are **delivery-driven**,
not continuous. Realistic estimate is ~10-20 min/day active ranging.

**Active state (during a delivery):**

| State | Current @ VDD=3.0V | Duty | Avg current |
|---|---:|---:|---:|
| UWB TX (1× per cycle, 150 µs) | ~200 mA | 1.5% | 3.0 mA |
| UWB RX (2× per cycle, 150 µs) | ~130 mA | 3.0% | 3.9 mA |
| MCU active | ~8 mA | 10% | 0.8 mA |
| Sleep | ~5 µA | 85% | ~0 |
| **Avg at module (peer anchor)** | | | **~7.7 mA** |
| Hub stump adds BLE forwarding | | | **+0.5-1 mA** |

**Battery side (3.7V Li-ion via LDO to 3.0V):**
- Same current as module (LDO drops 0.7V as heat)
- Peer anchor: 7.7 mA active
- Hub stump: 8-8.7 mA active (the BLE peripheral is steady-state
  forwarding, low load — see §5.4 disconnect-cache model)
- Sleep (between deliveries): ~50 µA

**Daily energy (delivery-driven use, ~10 min active):**
- ~12 mAh/day per anchor

**Annualised runtime:**

| Battery | Capacity | Runtime |
|---|---:|---:|
| 1× 18650 (default) | 3500 mAh | **~290 days = full cricket season** |
| 2× 18650 | 6500 mAh | ~540 days |
| 1× LiPo 1000 mAh | 1000 mAh | ~83 days (~3 months) |

**Lifecycle pattern:** charge each anchor at the start of the cricket
season (Apr-May). The 1× 18650 sees the whole season without
recharge. Off-season storage at ~50% charge for ~6 months. Estimated
~10-year service life with annual deep-cycle pattern.

---

## 5. Signal Chain

### 5.1 Per-cycle timing (100 Hz, ETSI-compliant)

One UWB cycle:

```
t=0      Ball transmits POLL frame (broadcast)
t=200µs  Anchor 1 transmits RESPONSE_1
t=350µs  Anchor 2 transmits RESPONSE_2
t=500µs  ...
t=1.4ms  Anchor 8 transmits RESPONSE_8
t=1.6ms  Ball transmits FINAL frame
         Each anchor now has the timing data to compute its own range
         (DS-TWR, clock drift cancelled by 2× round-trip)
t=1.8ms  Anchors send ranges → hub stump (UWB-data-mode burst)
t=2-3ms  Hub stump packs into one BLE notification → iPhone
t=10ms   Next cycle begins
```

**Duty cycle:** ball 4% TX (within ETSI 5% limit), per-anchor 2%.
See `docs/airtime-budget.md` for the derivation.

### 5.2 Inter-anchor sync

Wireless self-sync at 10 Hz via inter-anchor TWR:
- Hub stump initiates a sync burst every 100 ms
- Each peer anchor measures its range to hub via DS-TWR
- Combined with known anchor positions, hub computes per-anchor clock
  offset + drift
- FTS (Frequency-Tracking System) disciplined timer per anchor
- Result: anchor-to-anchor sync to ~100 ps (3 cm equivalent), no
  cabling, no GPS, no PTP

See `sim 07b` for the validation.

### 5.3 Hub-to-phone link

**Transport:** Bluetooth LE 5.0, single peripheral connection.

**Payload per cycle:** ~80 bytes
- 8 anchor ranges (16 bits each, fixed-point mm) = 16 bytes
- 8 NLOS-detection flags (1 bit each) = 1 byte
- 8 per-anchor timing offsets within cycle (16 bits each) = 16 bytes
- 1 cycle timestamp (microseconds, 32 bits) = 4 bytes
- 1 ball-side accelerometer event flag = 1 byte
- Padding / framing = ~42 bytes
- Total ~80 bytes × 100 Hz = ~64 kbps (well within BLE limits)

**Reliability:** BLE re-transmits + hub stump flash buffer if phone
disconnects. Phone catches up on reconnect by streaming missed cycles.

### 5.4 Phone is source of truth; flash is a disconnect cache

The data model is:

- **Primary path:** UWB peer → hub → BLE live notification → **phone-side
  persistent store** (SQLite / Core Data). Every cycle gets a monotonic
  `seq` number assigned by the hub; phone persists `{seq, timestamp,
  payload}` as it arrives. The user-facing record lives on the phone.
- **Backup path:** hub also writes each cycle to W25Q128 flash, append-only,
  using Zephyr FCB. Sector-aligned. The flash is *not* a queryable archive
  — it has no time index, no bookmarks. It just stores a contiguous
  sequence-ordered log.
- **Reconciliation path:** phone tracks `highest_seq_received`. On BLE
  reconnect after a drop, it reads the hub's `Status` characteristic
  (`{oldest_seq_in_flash, newest_seq, free_sectors}`), and if there's a
  gap, sends a `Control` request: "replay seq N+1 to current." The hub
  streams those records out of flash as a burst, phone slots them into
  its local store. UI scrubbing resumes seamlessly because the UI reads
  from local DB, not the hub.

**Why this model:**
- Phone has plenty of storage and compute — owns the record properly.
- Scrubbing the timeline is a local DB query → instant. No radio
  round-trip per scrub.
- Hub firmware shrinks: sequence counter (RRAM-persisted), append-only
  writes, replay-by-range. No queries, no indexing, no bookmarks.
  ~1 week of firmware work vs ~3-4 weeks for queryable-buffer design.
- Coexistence is easy: steady state is just forwarding (low BLE +
  low UWB load). Disconnect: BLE off, no concurrent radios. Reconnect:
  brief catchup burst (seconds at BLE 2M PHY), then back to steady
  state. The pathological "both radios saturated" case doesn't occur.

**Disconnect cache sizing:**
- 16 MB W25Q128 at our cycle throughput → survives any realistic BLE
  outage including whole-session disconnect (phone died, app force-
  quit, user forgot to start it). Phone gets everything on reconnect.

---

## 6. Algorithm Pipeline

### 6.1 Overview

```
   UWB ranges (per-anchor) ──┐
                             │
   Ball ADXL372 events ──────┼────► [EKF predict-update loop]
                             │           │
   Anchor positions ─────────┘           │
                                         ▼
                              [Smoothed trajectory state]
                                         │
                                         ▼
                              [Forward extrapolation past pad]
                                         │
                                         ▼
                              [LBW verdict + ellipse]
```

### 6.2 State estimation: EKF + RTS smoother

**Module:** `simulation/src/infinity_stumps/ekf.py` → `TrajectoryEKF`

**State vector:** 9-dimensional
```
x = [px, py, pz, vx, vy, vz, ωx, ωy, ωz]
    ─────────  ─────────  ──────────
     position    velocity    spin
       (m)       (m/s)       (rad/s)
```

**Dynamics model:** drag + Magnus + gravity ODE (`simulation/src/infinity_stumps/physics.py`)
```
dp/dt = v
dv/dt = -g·ẑ
        + (-½ρ·Cd·A·|v|·v) / m              ← drag
        + (½ρ·CL·A·|v|·(ω̂ × v)) / m         ← Magnus
dω/dt = 0                                    ← spin treated as constant
                                                (slow decay → process noise)
```

with `ρ = 1.20 kg/m³` (air density), `Cd = 0.40`, `CL_coef = 0.15`,
`m = 0.160 kg`, `A = π·r²` (cross-section of cricket ball).

Bounce: when `z ≤ 0` and `vz < 0`, apply coefficient of restitution:
- `vz' = -COR_vertical · vz` (COR_v = 0.55)
- `vx' = COR_horizontal · vx` (COR_h = 0.75)
- `vy' = COR_horizontal · vy`
- `z' = 0`

**EKF predict step:**
For each time advance `dt`:
1. Numerically integrate the ODE forward → new state `x_pred`
2. Compute Jacobian F = ∂x_pred/∂x via central differences
3. P_pred = F · P · F^T + Q · dt
4. Record (F, x_pred, P_pred) for the RTS smoother

**EKF measurement update (UWB range):**
For each per-anchor range arrival:
1. Predicted range: `r_pred = ||pos - anchor||`
2. Innovation: `y = r_obs - r_pred`
3. Measurement Jacobian: `H = (pos - anchor) / r_pred`, padded with zeros
4. Innovation covariance: `S = H·P·H^T + σ_range²`
5. Kalman gain: `K = P·H^T·S^-1`
6. State update: `x ← x + K·y`
7. Covariance update: `P ← (I - K·H)·P·(I - K·H)^T + K·R·K^T` (Joseph form)
8. Overwrite the filtered slot in history (the predicted is preserved
   in the RTS arrays)

**RTS smoother backward pass:**
After all measurements:
```
For k = N-1 down to 0:
    G[k]    = P_f[k] @ F[k+1]^T @ inv(P_pred[k+1])
    x_s[k]  = x_f[k] + G[k] @ (x_s[k+1] - x_pred[k+1])
    P_s[k]  = P_f[k] + G[k] @ (P_s[k+1] - P_pred[k+1]) @ G[k]^T
```

The smoothed series is the best estimate of the state at each time
using **all** measurements, not just past ones.

### 6.3 Handling TWR within-cycle stagger

Each cycle's 8 ranges aren't simultaneous — they're staggered ~150 µs
apart. The EKF handles this naturally: each per-anchor range arrival
triggers a `predict()` to the anchor's response time, then
`update_range()`. No batched approximation needed.

Within a 1.5 ms cycle, the ball moves ~45 mm at 30 m/s. Treating
ranges as simultaneous (the batch fit assumption) embeds ~22 mm RMS
systematic error per cycle. The EKF avoids this.

### 6.4 LBW prediction (post-impact)

**Module:** `simulation/src/infinity_stumps/lbw.py`

Triggered when the ball's ADXL372 detects pad impact (or by user
selecting a moment in replay):

1. **Get smoothed state at last pre-impact sample:** `x_pre = ekf.smoothed_state[-1]`
2. **Forward-integrate** the ODE from `x_pre` with no pad force,
   continuing until `x` crosses `STUMP_LINE_X = +10.06 m`
3. **Find crossing point:** linear interp gives `(t_stump, y_stump, z_stump)`
4. **Propagate covariance:** numerical Jacobian `J = ∂(y_stump, z_stump)/∂x_pre`,
   then `Σ_yz = J · P_pre · J^T`
5. **Compute 95% confidence ellipse** from eigendecomposition of `Σ_yz`
6. **Verdict:** sample the ellipse perimeter (128 points), classify each as
   inside / outside the stump rectangle (228 × 711 mm):
   - All inside → **HITTING**
   - All outside → **MISSING**
   - Mixed → **UMPIRE'S CALL**
7. **Cricket-rule preconditions:**
   - `pitched_in_line`: ball's bounce y within stump half-width
   - `impact_in_line`: ball position at pad impact within stump half-width
   - Final OUT = (pitched in line OR pitched outside off) AND impact in line AND HITTING

### 6.5 Noise model parameters

| Parameter | Value | Source |
|---|---:|---|
| σ_range (UWB) | 30 mm | DW3110 / DWM3001C datasheet |
| σ0_pos (initial) | 300 mm | Wide-open prior |
| σ0_vel (initial) | 5 m/s | Wide-open prior |
| σ0_spin (initial) | 50 rad/s | Wide-open prior |
| q_pos (process) | 1 mm/√s | ODE is nearly exact |
| q_vel (process) | 0.05 m/s/√s | Drag/Magnus model errors |
| q_spin (process) | 0.5 rad/s/√s | Slow spin axis variation |
| NLOS detection p_detect | 0.85 | Conservative chip claim |
| NLOS p_fp (LOS misclassified) | 0.02 | Conservative |
| NLOS drop probability | 0.5 | Chip can't decode |
| NLOS leakage bias | uniform(50, 200) mm | Untreated NLOS samples |

All values in `sim_realistic.py` / `sim_ekf.py` constants section.

---

## 7. Software Modules

### 7.1 `simulation/src/infinity_stumps/` — Python reference / sim implementation

| Module | Purpose |
|---|---|
| `geometry.py` | Anchor positions, pitch constants, GDOP helpers |
| `physics.py` | `BallParams`, `ball_dynamics` ODE, `integrate_trajectory`, `make_delivery` |
| `solver.py` | Reference batch multilat + batch trajectory fit (deprecated as primary) |
| `noise.py` | UWB ranging noise model + utility functions |
| `skeleton.py` | 14-bone batter model for realistic occlusion sims |
| **`ekf.py`** | **`TrajectoryEKF` (predict / update_range / update_bounce_z / smooth_backward) — production estimator** |
| `lbw.py` | LBW verdict logic, ellipse computation, cricket-rule preconditions |
| `plotting.py` | Matplotlib visualisation helpers |

### 7.2 `simulation/sims/` — Validation simulations

Each sim is standalone, writes outputs to `simulation/outputs/*.png`. See
`docs/status-2026-05-13.md` for the full inventory and results table.

The **production pipeline** is `sim_ekf` + `sim_lbw`. Other sims are
either:
- Reference / baseline (sim 03, sim_realistic)
- Architecture-rejection documentation (sim 06, sim 07)
- Exploration that didn't pan out (sim_ml)

### 7.3 Future: iPhone-side production code

Planned port (not yet built):
- **Language:** Swift 5+
- **Numerics:** Accelerate framework (LAPACK / vDSP) for ODE
  integration + matrix ops
- **ML (v2+):** CoreML for any learned components
- **Architecture:**
  - Background thread runs the EKF, processes incoming BLE notifications
  - UI thread renders SceneKit / RealityKit 3D overlay
  - Main app stores delivery records in Core Data / SQLite for replay
  - Delivery completion triggers `smooth_backward` → LBW verdict popup

---

## 8. Failure Modes & Mitigations

| Failure | Symptom | Mitigation |
|---|---|---|
| Anchor occlusion (player blocks LOS) | Few valid ranges per cycle | Huber loss + chip NLOS detection; EKF handles gracefully |
| BLE link drop | iPhone loses telemetry | Hub stump buffers to flash; phone re-syncs on reconnect |
| Ball antenna null at spin orientation | Periodic dropouts | Anchor diversity (8 anchors); rare for full delivery to be lost |
| Bowler hand on ball at release | UWB severely attenuated | Ignore first ~50 ms post-release; EKF init by next clean samples |
| Anchor moves mid-session | Position calibration stale | Detect via inter-anchor TWR drift; trigger recalibration UI prompt |
| Battery dies mid-session | Anchor falls silent | Other 7 still functional; EKF degrades gracefully to 7 ranges |
| iPhone app crash | Loss of UI / verdicts | Hub stump keeps logging; replay from flash on relaunch |
| User installs anchors at wrong height | Geometry assumption broken | Calibration step measures actual anchor positions; software adjusts |

### 8.1 Graceful degradation by valid range count

| Valid ranges per cycle | EKF behaviour |
|---:|---|
| 8 | Full update, optimal |
| 4-7 | Update with fewer measurements; slightly higher per-cycle σ |
| 1-3 | Skip update for this cycle; predict-only |
| 0 | Predict-only; uncertainty grows but trajectory continues |

The EKF naturally handles missing measurements — no special logic
required. The RTS smoother retroactively fills in dropouts.

---

## 9. Calibration

### 9.1 Anchor position calibration (one-time per setup)

User procedure:
1. Place anchors at intended positions (stump tops, PAI corners)
2. Open iPhone app → "Calibrate Pitch"
3. Walk the ball tag around the pitch perimeter for ~60 seconds
4. App runs a least-squares solver:
   - Unknowns: 8 anchor positions (24 dims, minus 6 fixed for ref
     anchor + axes)
   - Measurements: ~6000 ranges from various ball positions
   - Result: anchor positions to ~5 mm
5. App stores calibration; valid until anchors physically moved

### 9.2 Per-session sanity check

On session start, do a 30-second baseline:
- Ball tag placed at known position (e.g., on a popping crease)
- Compute expected ranges from calibrated anchor positions
- Compare to measured ranges
- Flag if σ > 60 mm (signals NLOS environment or anchor moved)

### 9.3 Coefficient of restitution (per-session, v2)

The pitch's bounciness varies (damp → 0.45, hard → 0.65). The iPhone
app can fit COR over the first 5-10 deliveries by comparing observed
post-bounce velocity (from UWB ranges bracketing the bounce) to
pre-bounce velocity. Subsequent deliveries use the calibrated COR.

Not in v1 (the EKF works with fixed COR_v = 0.55).

---

## 10. Interfaces

### 10.1 BLE service definition (hub stump → phone)

Custom service UUID: `TBD-0000-cric-uwb-hub-XXXXXXXXXXXX`

Four characteristics, mapping to the disconnect-cache data model (§5.4):

- **`Live`** (notify, ~90 bytes) — `{seq, timestamp_us, payload}` for
  each UWB cycle as it lands. Steady-state path.
- **`Control`** (write) — commands:
  - `replay {seq_start, seq_end}` — fill a gap from flash cache
  - `start_session`, `stop_session`, `start_calibration`, `reset_seq`
- **`Status`** (read) — `{oldest_seq_in_flash, newest_seq,
  free_sectors, battery_pct, fw_version, calibrated, anchor_count}`
- **`Session Metadata`** (read/write) — calibration values, anchor
  positions, pitch identifier, session ID

**Notification rate:** 100 Hz (one per UWB cycle). BLE connection
interval 7.5-15 ms accommodates. Payload ~90 bytes including framing
fits in one ATT MTU at standard 247-byte negotiation.

**Sequence counter:** monotonic, persisted to RRAM every ~10 s of
activity so it survives reboots without going backwards. Phone treats
seq as the authoritative ordering primitive; timestamps are
informational.

**Replay protocol:** phone writes `replay {N+1, current}` to `Control`,
hub streams matching records as `Live` notifications with their
original `seq` numbers (the phone tells them apart from live records
by checking seq < `current_at_request_time`). Streaming throttled to
not interfere with live cycle handling — typically completes in
seconds even for large gaps.

### 10.2 UWB-data-mode protocol (peers → hub)

Within the inter-cycle quiet period, each peer anchor sends:
- Its computed range to ball (16 bits, fp mm)
- Its NLOS-detection flag
- Its battery / temperature telemetry
- CRC

Hub aggregates 8 of these into one BLE notification.

### 10.3 iPhone app surface (placeholder; v1 UI not designed)

- Live 3D pitch view with ball trail
- Delivery list (date, type, verdict)
- Tap delivery → DRS-style replay with HIT/MISS/UMP overlay
- Export as MP4 (sharing)
- Calibration / setup wizard

---

## 11. Performance Envelope

### 11.1 Latency

| Path | Target | Notes |
|---|---:|---|
| Ball position estimate (live) | < 50 ms | EKF forward pass + BLE round-trip |
| LBW verdict after pad impact | < 1 s | Trigger → smoother → extrapolation → render |
| Calibration | < 90 s | One-time per pitch setup |
| Replay rendering | 60 fps | iPhone GPU has zero issue here |

### 11.2 Precision

See §1.3 and `docs/status-2026-05-13.md`.

### 11.3 Resource usage (iPhone)

Estimated, not yet measured:
- CPU: ~5-10% sustained (EKF per cycle is microseconds)
- Memory: < 50 MB per session
- Battery: ~5% per hour of active session (BLE is the dominant drain)
- Storage: ~5 MB per session (compressed)

---

## 12. Architectural Decision Log

Each decision links to its validation source. See full reasoning in
`CLAUDE.md` decisions list.

| # | Decision | Validation |
|---|---|---|
| 1 | Qorvo DWM3001C (vs QPK3000, Decawave, Apple U2, Murata) | Datasheet review + FiRa + ETSI + stock availability + dev kit = production part |
| 2 | 8 anchors (vs 12) | sim 02 — <2% gain not worth 50% cost |
| 3 | Wireless self-sync (vs cabled) | sim 07b — FTS at 10 Hz works |
| 4 | DS-TWR @ 100 Hz (vs TDoA, vs 150 Hz) | sim 07, `airtime-budget.md` |
| 5 | No precision IMU in ball | sim 06 |
| 6 | EKF + RTS smoother (vs batch fit) | sim_ekf, sim_lbw |
| 7 | Hub stump + iPhone (vs edge PC) | Cost + UX |
| 8 | Magnetometer-only spin path (v2) | iBall §3 + patent landscape |

---

## 13. Future Extensions (Roadmap)

### v2 (post-launch)

- **Magnetometer for spin analytics** — `BMM350` ball-side, iBall-style
  cone-fitting → spin axis + RPM. Adds coach-facing "your googly was
  X rps with Y° tilt" feature. ~£5 BOM addition.
- **Per-session COR calibration** — learn pitch bounciness in first 5-10
  deliveries.
- **Live broadcast graphics SDK** — let broadcasters embed our trajectory
  feed into their production. Forward-only EKF runs in real time.
- **Android app** — Kotlin / JNI port. Same algorithm.

### v3+ (speculative)

- **Player UWB tags** — track fielders and batter for run-out review
- **No-ball detection** — bowler foot crossing crease line
- **Edge detection** — sound sensor near stumps + UWB ball event
  cross-correlation for caught-behind
- **Multi-pitch venue mode** — manage 4-8 pitches from one phone
- **Cloud sync** — share session data across devices, team-level dashboards
- **Tightly-coupled UWB+IMU EKF** — if magnetometer-only proves
  insufficient (patent landscape permitting)

---

## 14. Glossary

| Term | Definition |
|---|---|
| **DS-TWR** | Double-Sided Two-Way Ranging — UWB ranging method that cancels clock drift via two round-trips |
| **EKF** | Extended Kalman Filter — nonlinear state estimator |
| **RTS** | Rauch-Tung-Striebel — backward smoothing pass over an EKF history |
| **NLOS** | Non-Line-of-Sight — UWB signal obstructed by a body, distorts range |
| **GDOP** | Geometric Dilution of Precision — how anchor geometry amplifies ranging noise into position noise |
| **PAI** | Protected Area Indicator — the four corner markers defined by Laws of Cricket |
| **DRS** | Decision Review System — the technology stack used in international cricket for umpire review |
| **CoR** | Coefficient of Restitution — fraction of vertical velocity retained after a bounce |
| **ETSI** | European Telecommunications Standards Institute — sets UWB duty-cycle limits |
| **FiRa** | Fine Ranging consortium — the FiRa 2.0 standard for interoperable UWB ranging |
| **TWR** | Two-Way Ranging — measures distance via timed round-trip |
| **TDoA** | Time Difference of Arrival — measures position via timing differences (rejected — sim 07) |

---

## 15. References

- iBall paper: Gowda et al., "Bringing IoT to Sports Analytics,"
  NSDI '17. https://www.usenix.org/conference/nsdi17/technical-sessions/gowda
- Qorvo DWM3001C datasheet + product brief: `docs/datasheets/`
- Cricket ball aerodynamics: Mehta, "Cricket ball aerodynamics: myth
  vs science," International Sports Engineering Conference, 2005.
- Laws of Cricket (ICC): https://www.icc-cricket.com/about/cricket/rules-and-regulations/playing-conditions
- ETSI EN 302 065-2 (UWB regulatory limits)
- See also: `docs/prior-art.md`, `docs/findings.md`, `docs/spec-v0.2.md`,
  `docs/airtime-budget.md`, `docs/phase1-2-test-plan.md`.

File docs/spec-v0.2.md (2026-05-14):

# System Spec v0.2

## Mission

**DRS for the rest of us.** Hawk-Eye is £100K+ and locked to
professional cricket. We deliver Hawk-Eye-class trajectory tracking and
LBW prediction at consumer prices, via a portable kit and a phone app.

## Prior art

Gowda et al. (NSDI '17, "Bringing IoT to Sports Analytics" — iBall)
established UWB + physics-fit + LBW extrapolation as published public
knowledge. They demonstrated 8 cm median (indoor, 2 anchors) and LBW
extrapolation at 22 cm 3D / 9.9 cm X (within ICC 10 cm tolerance) but
never productised. **Our contribution is execution**: 8 anchors (no
DoP collapse), modern Qorvo FiRa 2.0 silicon (~5× better raw σ),
outdoor validation, hub-stump topology, iPhone-native compute,
consumer pricing. See `docs/prior-art.md` for the full breakdown of
what we borrow vs add.

## Goal
17–22 mm 3D positional precision in clean LOS / **35 mm median, 78 mm
p95** under realistic occlusion, of a regulation cricket ball through
delivery, flight, bounce, and post-bounce, sampled at 100 Hz
(ETSI-compliant), in a portable system deployable at any ground.
LBW prediction target: **substantially under iBall's 22 cm 3D /
9.9 cm X-axis** at the stump line.

## Platform: Qorvo DWM3001C

Single 27×19.13×3.2 mm module integrating:
- DW3110 UWB transceiver (channels 5/9, FiRa PHY/MAC, 802.15.4z BPRF)
- Nordic nRF52833 SoC (Cortex-M4F @ 64 MHz, BLE 5)
- Planar UWB antenna + Bluetooth chip antenna
- 3-axis accelerometer (IMU) on-module
- 32.768 kHz crystal + power management on-module
- VCC 2.5–3.6 V, 48-pin castellation
- FCC/SRRC/ETSI certification (planned), nRF Connect SDK
- The DWM3001CDK dev kit *is* this module — dev kit = production part

## Anchor configuration: 8 anchors

| ID | Position | Z (mm) | Mount |
|---|---|---|---|
| A1 | Bowler off stump | 680 | Top of stump |
| A2 | Bowler leg stump | 680 | Top of stump |
| A3 | Bowler PAI off | 0 | Flush in-ground |
| A4 | Bowler PAI leg | 0 | Flush in-ground |
| A5 | Batter PAI off | 0 | Flush in-ground |
| A6 | Batter PAI leg | 0 | Flush in-ground |
| A7 | Batter off stump | 680 | **Hub stump** (sync master + BLE gateway + flash buffer) |
| A8 | Batter leg stump | 680 | Top of stump |

PAI positions: ±7.62 m longitudinal, ±1.53 m lateral (per Law 7).

## Architecture

- **Positioning: broadcast DS-TWR at 100 Hz.** One ball poll, 8
  staggered anchor responses, one ball final per cycle. Ball duty
  cycle 4%, per-anchor 2% — ETSI-compliant. TDoA was considered for
  500 Hz beacons but sim 07 showed it carries a ~120 mm intrinsic
  noise floor from hyperbolic GDOP + correlated reference noise; TWR
  wins. 150 Hz TWR was considered but breaches ETSI duty cycle (see
  `airtime-budget.md`).
- Sync: wireless via inter-anchor UWB ranging at 10 Hz, with FTS-style
  disciplined-timer correction at each anchor (no cabling). The
  **hub stump** (A7) is the sync master. See sim 07.
- **Topology: hub stump + iPhone.** One stump-top anchor acts as the
  system hub: UWB sync master, range aggregator (collects ranges from
  the other 7 over UWB-data-mode packets), and BLE gateway to the
  user's phone. The other 7 anchors are "dumb peers" running the same
  hardware with a simpler firmware image. The iPhone (or iPad) runs
  multilat + Huber physics fit + optional ML layers using Swift +
  Accelerate + CoreML. **No edge PC in the BOM.**
- Pipeline: ball ↔ 7 anchors (UWB ranging) + ball ↔ hub stump (UWB
  ranging) → 7 anchors → hub (UWB-data) → hub → iPhone (BLE) →
  physics fit on phone → DRS replay overlay on phone
- Update rate: 100 Hz UWB cycles. IMU dropped from v1 BOM (sim 06
  showed complementary-filter fusion hurts more than helps).
- Live broadcast overlay (if implemented) uses sliding-window fit on
  the same data stream — deprioritised; DRS replay is the primary
  product.
- Hub buffers ranges to internal flash when the phone is absent or
  backgrounded, so the system is a self-contained recorder by
  default — the phone catches up on reconnect.

## Precision budget (validated by sims 03, 05b, 07, sim_realistic, sim_ekf)

| Stage | 3D RMS | Source |
|---|---|---|
| Raw UWB ranging (TWR) | 30 mm σ | datasheet |
| TWR multilat, clean LOS | ~125 mm | sim 03 |
| TWR physics-fit, clean LOS @ 100 Hz | ~17–22 mm | scaled from sim 03 |
| TWR fit + occlusion (no mitigations) | ~225 mm | sim 05 |
| Batch fit (deprecated), realistic occlusion @ 100 Hz | 41 mean / 35 med / 78 p95 mm | sim_realistic n=30 |
| **EKF forward (live overlay)** @ 100 Hz | **47 mean / 47 med / 82 p95 mm** | sim_ekf n=30 |
| **EKF + RTS smoother (DRS replay)** @ 100 Hz | **47 mean / 48 med / 61 p95 mm** | sim_ekf n=30 |
| **EKF + RTS lateral (y-axis)** @ 100 Hz | **8.7 mm** mean \|err\| | sim_ekf n=30 |
| TDoA fit, perfect sync (rejected) | ~120 mm | sim 07 |

**Operational target: EKF + RTS smoother at 47 mm mean / 61 mm p95 /
8.7 mm y-axis** under realistic occlusion at 100 Hz. Forward-only EKF
runs in real time for live broadcast overlay; the RTS pass refines for
DRS replay. **The smoother beats the older batch fit on p95 (61 vs
78 mm) and lateral, at the cost of +6 mm on the mean.**

Headline 10–20 mm is the clean-LOS marketing number; the operational
number is what ships. Both are competitive with Hawk-Eye in match
conditions (independent audits put Hawk-Eye at 30–50 mm field accuracy,
despite a marketed 3.6 mm spec).

**The trajectory engine is the system's core technical IP.**

## BOM (rough, low volume)

| Item | Cost | Notes |
|---|---|---|
| Stump anchor (×4) | ~$120 ea | DWM3001C + 1× 18650 + flash + USB-C + enclosure. Identical hardware A1/A2/A7/A8; A7 runs hub firmware |
| PAI anchor (×4) | ~$135 ea | Same board, magnetic charging connector + sealed cylinder |
| Ball tag (×N) | ~$190 ea | DWM3001C + ADXL372 (±200g, bounce/pad/bat timing) + piezo high-g impact sensor (±10-50 kg, impulse for v_in recovery → physics-determines Z trajectory) |
| **Per-pitch** | **~$1,500** | Plus N balls. **No edge PC** — user supplies phone. |

## Open Phase 0 items
1. Sliding-window real-time filter (sim 04)
2. Multipath + occlusion model (sim 05)
3. IMU fusion (sim 06)
4. Sync engine modelling (sim 07)
5. Self-localisation (sim 08)
6. Patent landscape search
7. Qorvo applications engineering engagement

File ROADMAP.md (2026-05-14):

# Roadmap — Next Simulations

Prioritised list. Each entry has a Claude-Code-ready prompt and an exit
criterion. Tier 1 items are project-critical.

---

## TIER 1 — Project-critical unknowns

### Sim 04 — Sliding-window real-time filter

**Why:** Sim 03 used a batch fit on the complete trajectory. Live use
needs a recursive estimator that only sees past samples. If precision
loss is 2× we're fine, if 10× the real-time product is broken.

**Prompt:**
Read CLAUDE.md and simulation/src/infinity_stumps/. Create simulation/sims/04_sliding_window.py:

Reuse the trajectory generator and noise model from sim 03.
Implement a sliding-window physics-fit estimator that, at each time t,
fits the physics model to samples up to t only (try windows of 100,
200, full history).
Compare estimates against ground truth at each instant.
Also implement a 6-state Kalman filter (position + velocity) with
physics-driven process model.
Plot precision vs time for batch / sliding-200 / Kalman on a single
delivery and as Monte Carlo over 50 deliveries.

Exit: precision-penalty ratio (RMS real-time / RMS batch), and whether
the Kalman is competitive with the sliding-window fit.

### Sim 05 — Multipath and occlusion

**Why:** Previous sims assumed clean LOS. Real cricket has bowler-
in-stride, umpire, keeper, slips intermittently blocking paths.

**Prompt:**
Build simulation/sims/05_multipath_occlusion.py:

Add 6 cylindrical occluders (bowler, umpire, keeper, 2 slips, gully)
at realistic positions. Anchor-ball rays within 0.4 m of an occluder
are either dropped (50% chance) or get a +50 to +200 mm bias added.
Bowler occluder moves: behind stumps at delivery, advances 5 m down
pitch in 0.5 s.
Verify the range-based multilateration solver (TWR architecture, see
CLAUDE.md decision 4) is robust to fewer than 8 anchors.
Run trajectory recovery with this realistic model. Compare batch and
sliding-window precision against clean-LOS baseline.

Exit: numbers on (a) fraction of samples losing anchors, (b) precision
degradation factor, (c) whether 8 anchors is still enough.

### Sim 06 — IMU fusion

**Why:** The in-ball tag has a 6-axis IMU. Adding it should reduce the
parameter space and bridge UWB dropouts.

**Prompt:**
Build simulation/sims/06_imu_fusion.py:

Model a 6-axis IMU. Accelerometer reads body-frame accel + gravity
with σ_a = 0.05 m/s². Gyro reads body-frame angular rate with
σ_g = 0.01 rad/s plus bias random walk. 1 kHz sample rate.
Coordinate frames: ball rotates at ~25 rev/s. Integrate gyro for
attitude, transform accel to world, integrate for vel+pos.
Tightly-coupled EKF combining UWB ranges and IMU.
Test against sim 05's occlusion model.

Exit: precision comparison (UWB only) vs (UWB + IMU) under clean LOS
and occluded conditions. Clear answer on whether the IMU is required
or just nice-to-have.

---

## TIER 2 — Sync engine and system-level

### Sim 07 — Anchor sync error budget

**Prompt:**
Build simulation/sims/07_sync_budget.py. Each anchor has its own clock with crystal
drift (20 ppm, random-walk-plus-bias). Inter-anchor TWR at 10 Hz produces
noisy clock-offset observations (σ = 30 ps). Linear regression per anchor
predicts the relationship to master. When a ball beacon arrives, each
anchor timestamps it on its own clock; the predicted relationship
translates to a common frame.
Vary inter-anchor sync rate (1/10/100 Hz) and crystal stability
(TCXO vs XO). Recommend spec.
Exit: clear answer on sync rate / oscillator class for production spec.

### Sim 08 — Anchor self-localisation

**Prompt:**
Build simulation/sims/08_self_localization.py. Place anchors at nominal positions
+ random perturbations (~50 mm 1σ). Use known constraint distances
(stump width, PAI lateral spread, pitch length) plus measured pairwise
UWB ranges to estimate positions in a self-consistent frame. Run with
30 mm range noise. Use the estimated geometry for ball tracking — how
does error propagate?

Exit: residual self-loc error <30 mm per anchor; ball-tracking precision
degrades by <10% vs perfect-knowledge geometry.

### Sim 09 — Scheduling and airtime

**Prompt:**
Build simulation/sims/09_scheduling.py. Time-slotted airtime with 50 µs slots.
Inter-anchor sync: 28 exchanges every 100 ms. Ball beacons: every 2 ms.
Account for FCC/ETSI UWB duty-cycle limits (~5%). Stats on packet loss,
collision rate, latency.
Exit: prove schedule fits within regulatory limits with margin; quantify
expected packet success rate.

---

## TIER 3 — Refinement
- Sim 10 — Bounce model (variable pitch state)
- Sim 11 — Spinning antenna pattern
- Sim 12 — Different bowling styles (spin, swing)
- Sim 13 — Weather effects

## TIER 4 — Engineering scoping
- Doc 01 — Power budget from DWM3001C datasheet
- Doc 02 — Mechanical design (stump + PAI enclosures)
- Doc 03 — Formal patent landscape search

---

## How to use

1. `cd infinity-stumps`
2. Open Claude Code in the directory
3. Pick a sim, paste its prompt
4. Review generated code and outputs
5. Commit and move on. Don't run all of Tier 1 at once — review each.

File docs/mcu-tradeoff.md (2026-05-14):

# MCU choice & developer-onboarding model

**Decision (2026-05-14): stay on the Qorvo DWM3001C. Solve developer
onboarding by distributing pre-bootloadered boards — not by changing
silicon.**

## The question

Developer-onboarding friction: the nRF52833 needs an SWD probe + nRF
Connect SDK (Zephyr) to flash. There is no USB ROM bootloader, so a
*blank* board cannot be flashed over USB. We considered dropping the
DWM3001C for a **DWM3000** (UWB-only module) + an **Espressif ESP32-C6**
(USB ROM bootloader, Arduino / ESP-IDF ecosystem) to make the project
easier for open-source contributors to build and hack on.

## Why we stay on the DWM3001C

- **Ball-tag consistency.** The in-ball tag has the hardest power/size
  constraints in the system; nRF52-class silicon is the right fit there.
  ESP32 anchors + nRF ball = two MCU families, two toolchains, two
  firmware codebases — *worse* for contributors, not better.
- **Carrier-board elegance.** DWM3001C = pre-certified module, MCU<->UWB
  SPI internal, dev = production. DWM3000 + ESP32 means owning that SPI
  bus, placing two modules, a fatter board — permanent complexity for
  every builder, forever.
- **Battery life.** ESP32-C6 anchor modelled at **~130-210 days vs ~290**
  (DWM3001C). The UWB radio (DW3110) energy is identical; the loss is all
  in active-session MCU current. Standby is a wash (~52 µA vs ~50 µA —
  board housekeeping dominates, not the MCU). It breaks the "charge once
  per season" goal.
- **The onboarding problem has a cheaper fix** (below) — re-architecting
  the whole system to solve a one-time dev-setup step is the wrong lever.

## The onboarding model

- **Distribute pre-bootloadered boards.** Sell assembled / tested /
  flashed units at a sustaining margin, or otherwise provide pre-flashed
  boards. The one-time SWD bootloader flash happens at assembly /
  provisioning; the board then behaves like an Adafruit Feather
  (USB-flashable, UF2-style). This is the standard OSHW model — Adafruit,
  Sparkfun, Prusa all do exactly this, and CERN-OHL-S permits it.
- **The PCB fab can do the bootloader flash.** JLCPCB offers a PCBA
  firmware-flashing service — they program each board after assembly from
  a HEX/BIN you supply (~$8 setup + ~$8/hr labour). Requirements:
  accessible on-board SWD pads (the Tag-Connect TC2030 block) and a
  support confirmation that they can target the nRF52833 over SWD,
  including the APPROTECT `--recover` step. So fab + assembly + flash can
  be a single order — no in-house provisioning line needed. A standalone
  J-Link + scripted `nrfjprog` stays as the fallback and for dev boards.
- **Keep BOM / Gerbers / firmware fully public.** Self-builders get a free
  DIY path; only someone hand-assembling *and* doing bare-metal bring-up
  needs a ~£15 probe — and that person already owns one.
- **BLE DFU** already covers field firmware updates for the consumer path.
- **Going-vendor caveat:** selling hardware brings real obligations —
  finished-product EMC / CE / FCC marking, warranty, returns, inventory,
  support load. De-risk by starting on Tindie / via an existing shop
  before becoming a hardware company.

## Antenna-delay calibration is not vendor lock-in

It was briefly considered a vendor-only value-add; it is not:

- The DWM3001C is **factory-calibrated** for antenna delay (stored in
  OTP). The antenna is on-module; the carrier board adds none.
- Any residual **self-calibrates in the field**: the 8 anchors sit at
  Laws-of-Cricket positions and already run inter-anchor TWR for time
  sync — per-anchor delay solves by least-squares against the known
  geometry. Zero user effort, no jig, no known-distance procedure.

The pre-flashed board's value is assembly + bootloader + test + QC +
support + "works out of the box" — not an artificial calibration moat.

## Open / not yet decided

- **Route USB D+/D-/VUSB** from the module to the USB-C connector?
  Enables USB-DFU *after* the one-time SWD bootstrap. The module exposes
  them (DWM3001C pins 18 VUSB / 19 USB_N / 20 USB_P). Currently §4.2's
  USB-C is power-only. Touches anchor-board §4.2 and the §4.7 reset/button
  scheme if double-tap-reset DFU is wanted.

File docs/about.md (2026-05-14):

# About Infinity Stumps

> **What this is, why we're building it, and why everything we make
> is deliberately, publicly, dated prior art.**

---

## What this is

Infinity Stumps is a low-cost, open-source ball-tracking and LBW
prediction system for cricket. It does what Hawk-Eye does — track
the ball in 3D, predict trajectories, render DRS-style replays — but
at roughly 1/30th the cost (~£1,500 vs £100K+), with a kit small
enough to fit in a backpack, running on a consumer phone.

The whole point is **accessibility**. The 99% of cricket that's played
in clubs, schools, academies, parks, garages, and back gardens has
never had access to DRS-level analytics. We're building the system
that brings it to them.

---

## What we're building (v1)

Eight UWB anchors placed at standard cricket-pitch positions (4 stump
tops, 4 ground-level corner markers). A tag inside the ball. A
phone-side app that does all the math. That's the whole system.

- **Hardware:** ~£300 of electronics per pitch, ~£60 per ball
- **Software:** open-source EKF + RTS smoother + LBW prediction pipeline
- **App:** native iOS first, Android to follow
- **Power:** one charge per cricket season
- **Setup time:** walk the ball around the pitch for 60 seconds to
  calibrate anchor positions
- **Performance** (simulated, n=30):
  - 9 mm lateral median error at the stump line
  - 96.7% exact LBW verdict accuracy
  - Zero false-positives across 30 simulated deliveries

See `architecture.md` for the technical detail, `status-2026-05-13.md`
for current results.

---

## Mission

**DRS for the rest of us.**

That's the line. Three audiences benefit:

1. **Local clubs** — make accurate calls in friendly matches and
   league cricket where umpires can't review video, settle the bar
   debate about whether that LBW was out.
2. **Schools and academies** — train juniors with real feedback. "You
   beat the bat by 22 mm — try to pitch 30 mm wider next time."
3. **Coaches and individual players** — practice with metrics that
   used to require an international stadium.

Three audiences we are NOT serving (Hawk-Eye does these well already):

1. International cricket broadcasters
2. Stadium installations
3. Ball-by-ball broadcast graphics for live TV at full international quality

We don't compete with Hawk-Eye on its turf. We unlock cricket's
**other 99%** of use cases — markets where £100K+ stadium installs
are impossible.

---

## Open by design

This project is built to be as open as physically possible:

### Code

- Repository **public from day one** on GitHub
- License: **Apache 2.0** for software, **CERN-OHL-S** for hardware
  designs, **CC-BY-4.0** for documentation
- All commits dated, signed, retained
- Issues, design discussions, and decisions tracked in public

### Hardware

- Schematics, PCB Gerbers, BOMs all published in repo
- 3D-printable enclosure files (STL + STEP) under CC-BY
- Reference firmware open
- Parts list maps to off-the-shelf suppliers (no proprietary modules
  except the Qorvo silicon itself, which is freely orderable)

### Algorithms

- Every line of the EKF, RTS smoother, LBW verdict logic — published
- Simulation harnesses (`simulation/sims/`) demonstrate the architecture works
- All sim outputs (per-delivery error analyses, confusion matrices,
  N=30 boxplots) committed to the repo as PNGs with their generating
  code

### Decisions

- `CLAUDE.md` has the decision log
- `docs/findings.md` documents what worked and what didn't, with
  per-sim numbers
- `docs/prior-art.md` credits iBall and details the techniques we
  borrowed
- Architectural decisions that didn't work (TDoA, complementary-filter
  IMU fusion, piezo-velocity recovery) are documented as
  **rejection-rationale prior art**, not erased

---

## Why deliberately establishing prior art

The cricket-tech patent landscape is dense. Hawk-Eye, Catapult,
STATSports, ESPN, Sony, Wilson, and many others hold patents that
make any new entrant nervous. iBall (Gowda et al., NSDI '17)
established the **core idea** of UWB + physics-fit + LBW
extrapolation as public prior art — but every system contains
hundreds of subsidiary innovations that could individually be
patented by an aggressive entity later.

**We don't want to file patents.** We're not a patent-holding company,
we're not interested in litigation, and patent prosecution costs
~£10-30K per claim that we'd rather spend on shipping product.

**But we also don't want anyone else patenting things we built.**
Specifically: someone could read this repo, take a specific
technique, claim it as their own invention, file a patent in the US
or EU, and then sue us (or future users) for infringement.

The defence against that scenario is **public, dated, detailed prior
art** — establishing that the technique was already publicly
disclosed before any later patent's priority date. Once something is
publicly disclosed with a verifiable date, no one can validly patent
it.

### Specific techniques we are establishing as prior art

Each of these is documented in this repo with a specific date and
commit hash. If anyone files a patent later claiming any of these,
this repo's git history serves as defensive prior art:

1. **Hub-stump system topology** — one anchor in a multi-anchor UWB
   system acting as sync master + range aggregator + BLE gateway,
   integrated within a stump-shaped housing. (`docs/architecture.md`,
   `CLAUDE.md` decision 7, May 2026)
2. **EKF + RTS smoother applied to cricket ball trajectory** —
   continuous Extended Kalman Filter over (position, velocity, spin)
   using a drag+Magnus+gravity ODE, with backward Rauch-Tung-Striebel
   smoothing applied for replay quality.
   (`simulation/src/infinity_stumps/ekf.py`, May 2026)
3. **DRS-style verdict with uncertainty ellipse from EKF covariance
   propagation** — applying the EKF's smoothed covariance through a
   numerical Jacobian of the forward-extrapolation function to produce
   a 95% confidence ellipse at the stump line, classified against the
   stump rectangle for HIT / MISS / UMPIRE'S CALL verdict.
   (`simulation/src/infinity_stumps/lbw.py`, May 2026)
4. **Phone-side disconnect-cache reconciliation protocol** — UWB
   anchor (hub) maintains a sequence-numbered append-only log; phone
   tracks `highest_seq_received` and requests gap-fill on reconnect.
   (`docs/architecture.md` §5.4, §10.1, May 2026)
5. **FiRa ranging + thin TDMA data layer for cricket** — using
   FiRa-compliant secure ranging for measurement and a thin
   fixed-schedule TDMA layer on the 802.15.4z PHY for peer-to-hub
   data exchange in a sports-tracking context.
   (`docs/architecture.md` §3.3, May 2026)
6. **TWR-staggered EKF updates handling within-cycle motion** —
   propagating the EKF state by ~150 µs per anchor measurement
   within a single ranging cycle to account for ball motion across
   the staggered TWR exchange. (`simulation/src/infinity_stumps/ekf.py`, May 2026)
7. **iBall-borrow techniques applied to multi-anchor cricket UWB:**
   Bouncing constraint, AoA / PDoA fusion roadmap, DoP-weighted
   residuals, magnetometer cone-fitting for spin —
   each explicitly mapped from iBall's 2-anchor research prototype
   to our 8-anchor production architecture.
   (`docs/prior-art.md`, May 2026)
8. **One-charge-per-cricket-season power architecture** — sizing of
   anchor electronics + battery such that runtime exceeds a complete
   cricket season (~6 months) on a single charge, enabling a
   service-once-per-year operations pattern.
   (`docs/architecture.md` §3.5, May 2026)

### Mechanisms for making prior art durable

1. **Public GitHub repository** — searchable, dated, archived by
   GitHub itself. Repository activity is part of the public record.
2. **Defensive publication via IP.com** (planned) — paid registration
   service that creates an unimpeachable timestamped publication
   record specifically designed for defensive prior art.
3. **Conference / workshop submission** (planned) — submit to UWB
   conferences (e.g., IEEE ICCWAMTIP, SIGSPATIAL), getting an academic
   publication record.
4. **arXiv preprint** (planned) — a clear, technical paper describing
   the system architecture and results, citing iBall and establishing
   our specific additions as prior art.
5. **Mirror to archive.org / Internet Archive** — periodic snapshots
   so the record exists independently of GitHub.
6. **Project blog posts with date-stamped publication** to a domain
   we control, for any technique not adequately covered by the above.

The combined effect: anyone trying to patent any of the techniques
above after May 2026 would face well-documented public prior art at
multiple levels of formality.

---

## License

- **Software** (`src/`, `simulation/sims/`, etc.): Apache License 2.0
- **Hardware designs** (PCB / mechanical / enclosure files):
  CERN Open Hardware License Strongly Reciprocal (CERN-OHL-S) v2
- **Documentation** (`docs/`, `README.md`, etc.):
  Creative Commons Attribution 4.0 (CC-BY-4.0)

The hardware license is "strongly reciprocal" — anyone who modifies
the hardware designs and distributes the modified version must also
publish their modifications under the same license. This is the
hardware equivalent of GPL; it prevents the open hardware from being
co-opted into a closed product.

---

## What "open" doesn't mean

A few clarifications:

- **Open ≠ free.** We may sell pre-built kits, charge for support,
  build a commercial app on top of this open core. Open source
  doesn't preclude commercial activity.
- **Open ≠ unsupported.** A commercial entity may form around the
  project to provide warranty, certification, and support. This is
  desirable — open hardware needs commercial actors to scale.
- **Open ≠ uncontrolled.** Trademark, branding, and certification
  marks may be protected. The "Infinity Stumps" name itself may become
  a registered trademark. Open architecture, controlled brand.
- **Open ≠ infinite forks acceptable.** Forks that confuse users
  (look-alike products on Amazon, knock-off kits) are bad for the
  ecosystem. The license + trademark combination is designed to allow
  technical forks while constraining commercial confusion.

---

## How to use this

If you're an **academic researcher** wanting to build on this:
clone the repo, run `simulation/sims/sim_lbw.py`, cite the prior-art document.

If you're a **hardware hacker / maker** wanting to build a kit:
the BOM (`docs/bom.md`) and architecture (`docs/architecture.md`)
together are sufficient to source parts and design a prototype.
Phase 1+2 firmware bring-up (`docs/phase1-2-test-plan.md`) describes
the validation sequence.

If you're a **club / school / coach** wanting the finished product:
this is being built. Watch for the v1 launch once hardware validation
is complete. Contact the project for early-access waitlist.

If you're a **patent attorney** evaluating prior art on behalf of a
competing entity: hello. Every meaningful technical claim in this
document is dated, version-controlled, and timestamped via GitHub's
infrastructure. The repository's full history is available at
`https://github.com/[USERNAME]/infinity-stumps` (link to be published
when the repo goes public).

---

## Contributing

PRs welcome. The project is built around clear documentation, dated
decisions, and explicit reasoning. Match that style and your
contributions will land easily.

For substantial architectural changes, open an issue first to
discuss. For routine fixes, just open a PR.

---

## Acknowledgements

- **iBall (Gowda, Dhekne, Shen, Roy Choudhury, Yang, Yang, Golwalkar,
  Essanian — NSDI '17)** — the foundational paper this project
  productises. Their open publication made everything we're doing
  possible.
- **Qorvo** — for the DWM3001C module and the willingness to sell it
  to small-volume buyers.
- **The Laws of Cricket (ICC)** — for being precisely written enough
  that we could calibrate the system geometry directly to them.

---

## Project status

- **Phase 0 (simulation):** ✅ Complete (May 2026)
- **Phase 1+2 (hardware bring-up):** 🔄 In progress
- **Phase 3 (full-pitch outdoor validation):** ⬜ Pending hardware
- **Phase 4a (3D-printed ball shell):** ⬜ Pending hardware
- **iOS app:** ⬜ Architecture validated, no code yet
- **v1 launch:** ⬜ Pending hardware validation

See `docs/status-2026-05-13.md` for the current state in detail.

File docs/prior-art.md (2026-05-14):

# Prior Art — iBall (Gowda et al., NSDI '17)

**Paper:** "Bringing IoT to Sports Analytics"
**Authors:** Mahanth Gowda, Ashutosh Dhekne, Sheng Shen, Romit Roy
Choudhury (UIUC) + Xue Yang, Lei Yang, Suresh Golwalkar, Alexander
Essanian (Intel)
**Venue:** 14th USENIX Symposium on Networked Systems Design and
Implementation (NSDI '17), Boston, March 2017
**URL:** https://www.usenix.org/conference/nsdi17/technical-sessions/gowda

**This paper is the foundational prior art for our system.** It
establishes the core idea (UWB ranging + physics-constrained
trajectory fit + LBW extrapolation for a cricket ball) as published
public knowledge. We are *not* patenting that combination. We *are*
shipping a productised, outdoor-validated, consumer-priced version
of what they prototyped.

---

## What iBall built

**Hardware**
- Intel Curie board (IMU + UWB radio) embedded in a hollowed-out
  cricket ball, halves glued shut, USB pigtail for charging
- Decawave UWB radio (gen 1), 6.5 GHz, 802.15.4-compliant
- Only **2 anchors** placed at the wickets (they believed additional
  anchors on the field of play were infeasible due to player
  interference)
- Anchors used 4-antenna MIMO for Angle-of-Arrival (AoA)
- Magnetometer for spin tracking (BMM150)
- IMU at 70 Hz, UWB ranging + AoA at 150 Hz

**Algorithm**
1. UWB ToF → range from 2 anchors → "tube" of possible positions
   (1-D underdetermined with only 2 anchors)
2. Add physics: drag + Magnus + gravity ODE as 6-parameter motion
   model (x₀, y₀, z₀, vₓ, v_y, v_z)
3. Add **bouncing constraint**: z = 0 at bounce (detected from
   accelerometer)
4. Add **AoA constraint** from MIMO anchor
5. **DoP-weighted residuals** (1/√DoP) — downweight ranges when the
   geometry collapses (mid-flight when anchor lines become collinear)
6. Non-linear gradient descent over 6 params; resolve AoA integer
   ambiguity by checking against ToF
7. **Magnetometer-based spin**: gyros saturate beyond ~6 rps but
   cricket spin is up to 25 rps. Trick: in free-fall the magnetometer
   sees a cone-shaped trace around the rotation axis. Fit a cone to
   3 consecutive measurements to get axis + rate.

**Results (indoor, ViCon ground truth)**
- Median 3D location error: **8 cm**
- Per-axis: 4.5 cm X, 3.4 cm Y, 2.4 cm Z (Z is best because of
  bouncing constraint)
- LBW trajectory extrapolation: **22 cm 3D / 9.9 cm X-axis** (ICC
  tolerance is 10 cm, so feasible "barely")
- Speed estimation: 0.4 m/s median error
- Spin orientation: 11.2° median cumulative angle error
- Cumulative angle: 1% mean, 3.9% max
- Player tracking (clip-on UWB): 1.2 m median, up to 80 m from
  anchors

**Explicit limitations they acknowledge**
- **Indoor only** — outdoor multipath/aerodynamics never validated
- Max 45 mph / 20 m/s ball speed (pro is 90 mph / 40 m/s)
- Max 12 rps spin (pro is up to 25 rps)
- 75-90 min battery
- Custom hollowed cricket ball, not a professionally manufactured one
- DoP issues in middle of flight
- Indoor multipath may have helped AoA accuracy artificially

---

## What we do differently

| Dimension | iBall 2017 | Infinity Stumps 2026 | Reason |
|---|---|---|---|
| Anchors | 2 | **8** | DoP collapse with 2 anchors; sim 02 says 8 is the sweet spot |
| UWB silicon | Decawave gen-1 | Qorvo DW3110 (DWM3001C module) | ~5× better raw ranging σ (30 mm vs 150 mm), FiRa / 802.15.4z, CIR access for NLOS detection |
| Topology | Anchors → backend PC | Hub stump → iPhone | No edge compute; consumer product |
| Sync | n/a (TWR sync-free) | Wireless inter-anchor TWR sync | Multi-anchor sync was their open problem too |
| Sample rate | 150 Hz (incl. AoA) | 100 Hz | ETSI duty-cycle limit (see `airtime-budget.md`) |
| Occlusion handling | Acknowledged | Huber loss + chip NLOS detection + realistic skeleton sim | Their indoor setup masked the occlusion problem |
| Outdoor validation | Punted to future work | Operational target (Phase 1+2) | The point of the project |
| Spin tracking | Magnetometer + cone-fitting | **Not yet** — ADXL372 is impact-only | v2 candidate, see below |
| LBW prediction | Claimed feasible at 22 cm/9.9 cm | Target: substantially under | Their explicit benchmark |
| **Location error** | **8 cm median (indoor)** | **3.5 cm median (sim, outdoor occlusion)** | sim_realistic n=30 |

---

## What we should borrow (and one thing we should add)

Techniques iBall validated that we should fold into our pipeline, plus
one new piece of sensing they didn't have:

### 1. Bouncing constraint (HIGH priority)

When the ball bounces, z = 0 at that timestamp. This is a strong
constraint — one point on the trajectory is *pinned* to within ranging
noise. iBall's Z-axis error was the best of all axes (2.4 cm) largely
because of this.

**For us:**
- Detect bounce from ADXL372 impact spike (we already log this)
- Add a soft constraint to `fit_trajectory`: residual `(z(t_bounce) - 0)² / σ_z²`
- Should improve Z-axis error specifically and tighten LBW predictions
- Effort: ~1 day in `simulation/src/infinity_stumps/solver.py`

### 2. AoA / PDoA fusion (HIGH priority)

iBall's AoA from MIMO anchors gave them a second observable per
anchor, letting them recover from DoP collapse. The Qorvo DW3110
chip supports **PDoA (Phase-Difference of Arrival)** when configured
with paired antennas. Same mathematical primitive.

**For us:**
- Add a 2-antenna config to the hub stump (or all stump anchors)
- Each ranging exchange also returns PDoA → 1 angle measurement per
  anchor
- Add AoA residual to `fit_trajectory`:
  `(cos(θ_measured) - cos(θ_predicted))² / σ_aoa²`
- iBall used 18 cm antenna separation to get unambiguous AoA. Our
  stump cross-section is ~36 mm wide, so we'd need a separate antenna
  bar above the stump (a few cm of horizontal aluminium)
- Effort: hardware design + ~1-2 days code
- Expected improvement: substantial reduction in mid-flight DoP error,
  better LBW extrapolation

### 3. DoP-weighted residuals (MEDIUM priority)

iBall weighted each range residual by 1/√DoP. We use Huber loss,
which is a different mechanism (suppresses outliers). They're
complementary — Huber for NLOS rejection, DoP weighting for geometric
quality.

**For us:**
- Compute DoP per timestep (already have GDOP code in `geometry.py`)
- Weight `fit_trajectory` residuals by 1/√DoP
- Effort: ~half day
- Expected improvement: modest mid-flight tightening; worth doing

### 4. High-g piezoelectric impact sensor (BEYOND iBall — HIGH priority)

This isn't borrowed from iBall — it's a step beyond them. iBall used a
generic IMU which saturated on real cricket impacts, so they had no
information from the bounce force itself.

**The mechanism:** with a non-saturating impact sensor, integrating its
spike over the ~0.5 ms contact yields the velocity change Δv at the
bounce. Coefficient-of-restitution physics then gives `v_in_vertical =
-Δv_vertical / (1 + COR_vertical)` — the ball's incoming vertical
velocity at the bounce moment. Combined with the bounce timestamp + the
known gravity vector + the bounce (x, y) from multilat, the **entire
z-trajectory becomes physics-determined**, bypassing the UWB anchors'
weak vertical baseline (GDOP_z ≈ 8 at mid-pitch).

**Sensor candidates:**
- Piezoelectric: PCB Piezotronics 350M77 (±50,000g), Meggitt Endevco
  7270A series (±60,000g)
- MEMS high-g: Silicon Designs / Endevco 7298A (±60,000g)
- PVDF film: wrapped inside ball shell, near-zero added mass, charge-mode

**Implementation:** dual-accelerometer ball-side: ADXL372 (±200g) for
spike *timing* and impact classification (pad vs bat vs bounce);
piezoelectric (±10-50 kg) for the actual *impulse measurement* that
yields v_in.

**Physics caveats — what the simple model gets wrong:**

The textbook formula `v_in = -Δv / (1 + COR_v)` treats COR_v as a known
constant and assumes the impulse is purely vertical. In real cricket
neither is true:

1. **COR varies session-to-session and within a session.** Pitch
   moisture (damp pitch → ~0.4-0.5), ball wear (new → ~0.6, worn → ~0.5),
   impact velocity (Hertzian softening at high v), temperature.
   Mitigation: **per-session COR calibration.** First 5-10 deliveries
   collect (Δv_piezo, v_in_uwb-bracketing); solve for COR_v that
   minimises (predicted - observed). Use that for the rest of the
   session. One-parameter fit, easy.
2. **Impulse is a vector, not a scalar.** A spinning ball with pitch
   friction has tangential impulse component. Magnitude-only piezo
   over-reads |Δv_z| by ~5-15%. Solutions:
   - **3-axis impact sensor (recommended)** — three single-axis piezos
     at perpendicular orientations, or a tri-axial MEMS high-g sensor.
     Direct vector impulse, no decomposition assumed. ~£30 ball-side.
   - Alternative: IMU orientation + assumption of pure normal impulse —
     free but breaks down precisely when spin matters most.
3. **Spin/slip at contact** transfers horizontal impulse not captured
   by the simple formula. Model mismatch grows with spin rate;
   typically 0.02 × spin_rps m/s additional noise on v_in.

**Realistic noise model on the recovered v_in:**

```
σ_v_in² = σ_impulse_integration² + σ_COR² + σ_spin_mismatch²

σ_impulse_integration  ≈ 5% of |Δv|          (sensor accuracy)
σ_COR_propagated       ≈ |v_z| / (1+COR) × σ_COR  (≈5% for σ_COR=0.05)
σ_spin_mismatch        ≈ 0.02 × spin_rps     (model gap)

⇒ per-delivery σ_v ≈ 0.6 m/s (no spin) to 0.85 m/s (max cricket spin)
```

The sim now uses this per-delivery noise model.

**Expected impact:** Z fit error drops from current ~60 mm median to
single-digit mm on low-spin deliveries; modest improvement on high-spin
deliveries where the simple impulse-CoR model has the largest mismatch.
Lateral and 3D LBW errors tighten correspondingly. Cost: +~£30 ball-side
(3-axis piezo), modest PCB area, no power needed (piezo is
self-generating).

This is the **single biggest precision lever** we have on top of iBall.

---

### 5. Magnetometer-based spin tracking (v2)

If we ever want spin analytics (revolutions, axis, "wobble"), iBall's
magnetometer + cone-fitting trick is the right approach because gyros
saturate at cricket spin rates. They achieved 11° axis error and
1% cumulative angle error.

**For us:**
- Adds magnetometer to ball-side BOM (BMM150 or modern equivalent)
- Implements the cone-fitting algorithm
- v2 territory — don't do until v1 location tracking is in users' hands

---
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

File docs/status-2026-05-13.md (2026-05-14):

# Infinity Stumps — Status Summary (May 13, 2026)

## Mission

**DRS for the rest of us.** Hawk-Eye-class ball tracking + LBW prediction
at ~1/30th the cost (~£1,500 vs ~£100K+), running on a consumer phone.

## Headline numbers

### Trajectory tracking (sim_ekf, n=30 @ 100 Hz, realistic occlusion)
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

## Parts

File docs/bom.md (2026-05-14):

# Infinity Stumps — Bill of Materials (active)

> Living document. Update freely as components / suppliers / volumes change.

**Last reviewed:** 2026-05-14
**Volume assumption:** 100 pitches (prototype / low-volume pricing)
**Currency:** GBP

---

## Per-pitch BOM summary

| Item | Qty | Unit £ | Subtotal £ | Notes |
|---|---:|---:|---:|---|
| Stump anchor | 4 | 31.20 | 125 | A1, A2, A7, A8 — **identical hardware**; A7 runs hub firmware |
| PAI ground anchor | 4 | 39.00 | 156 | A3-A6 — same board, magnetic connector + sealed IP67 housing |
| Ball tag | (per ball) | 53 | — | Add N × £53 for N balls |
| **Per-pitch electronics** | | | **£281** | Before balls and enclosures |
| Enclosures + assembly | × 8 | ~£40 | 320 | Stump caps + PAI housings + labour |
| **Per-pitch total (8 anchors + housings)** | | | **~£601** | Plus N balls @ £53 each (+ shell) |

For a club pitch with 6 game balls: **~£920**. For a single-ball training setup: **~£655**.

> **One board, all eight anchors.** The stump anchor and the PAI anchor
> are the *same PCB* — the PAI variant just swaps the USB-C receptacle
> for a magnetic charging connector and uses a sealed housing. The hub
> (A7) is firmware-only: every board is built identically (flash
> populated) and any one is hub-promotable by reflashing. See
> `hardware/anchor-board/README.md` for the board design.

---

## Stump anchor BOM (A1, A2, A7, A8 — 4× per pitch, identical hardware)

This is the single board design used at every anchor position. Full
schematic-level part list (≈40 passives, pin allocation, layout rules)
is in `hardware/anchor-board/README.md`.

| Component | Part number | £ each | Notes / supplier |
|---|---|---:|---|
| UWB+BLE+MCU module | Qorvo DWM3001C | 18.00 | DW3110 UWB + nRF52833 BLE/MCU. **Integrates a 3-axis accelerometer and the 32.768 kHz LFXO crystal** — no separate parts needed. Available from stock. Same module as the DWM3001CDK dev kit. Digi-Key / Mouser. |
| 18650 Li-ion cell | Panasonic NCR18650B 3400 mAh | 4.00 | Or equivalent. Genuine cells only. |
| 18650 holder | Keystone 1042 | 0.50 | Single-cell, with leads |
| Battery protection IC | DW01A + 8205A pair | 0.30 | Over-charge / over-discharge / over-current |
| Charge controller | TI BQ24074 | 1.50 | USB-C input, Li-ion CC/CV. 1.5 A max charge. |
| 3.0 V LDO | TI TLV75530PDQNR | 0.40 | Low-IQ, 500 mA. Powers DWM3001C from battery. |
| USB-C receptacle | GCT USB4105-GF-A | 0.40 | Standard CC1/CC2, no DP/Alt-Mode |
| USB-C ESD | TI TPD2E2U06 (CC lines) + VBUS TVS diode | 0.30 | CC1/CC2 ESD array + a dedicated VBUS surge clamp. Replaces the originally-specced TPD4S014 — a USB data-port protector, the wrong fit for this power-only port. Critical for outdoor / human-handled product. |
| 16 MB SPI flash | Winbond W25Q128JVSIQ | 1.00 | Disconnect cache (not archive). See architecture.md §5.4. **Populated on every board** — used only by hub (A7) firmware, but fitting it everywhere makes any anchor hub-promotable and keeps a single assembly BOM. |
| Flash power load switch | TI TPS22916C | 0.20 | Gates flash VCC in deep sleep. One GPIO controls it. Saves ~1 µA in deep-power-down mode. |
| Tactile power button | Alps SKHHALA010 | 0.10 | Side-mounted, IP67-rated |
| RGB status LED | Würth 150141 series | 0.10 | PLCC-4 3.2×2.8 mm, common-anode. Confirm the exact orderable against the `LED_RGB_Wuerth-PLCC4…150141M173100` footprint. |
| SWD tag-connect footprint | Tag-Connect TC2030-NL | 0.10 | No connector on board, just pads (J8). The dev-rail 2×5 SWD header is on the break-off rail — see note below. |
| Passives (47 parts) | 19 caps / 26 resistors / 1 ferrite / 1 TVS | 0.80 | Full itemised list in `hardware/anchor-board/README.md` §4. Exact count from completed schematic capture: module decoupling, charger network (incl. ILIM/ITERM/TMR/ISET program R's), protection, USB-C ESD + VBUS TVS, VBAT sense divider, LED limit R's, button debounce, 3V0 bulk. |
| PCB (4-layer, ~25×145 mm) | PCBWay / JLCPCB | 3.50 | Tall-and-thin to slide vertically inside the stump. At 100-piece volume. |
| **Subtotal silicon + PCB** | | **31.20** | Excludes enclosure + assembly. DWM3001C integrating the accel + crystal drops ~£1.25 of discretes and ~£8 of module cost vs QPK3000. |

The **hub role (A7) is firmware-only** — no hardware delta. Every board
is built identically with the flash + load switch populated, so any
anchor can take the hub role (or be swapped in as a hub replacement) by
reflashing. There is no separate hub SKU.

**Break-off dev rail — not in the production cost.** The schematic also
carries a V-scored dev rail (anchor-board README §7): J2 2×5 SWD header,
J3 UART header, J4 GPIO breakout, J5 3V0 current-shunt jumper, J6
LED-disable jumper, J7 reset/boot pads. These are populated only on dev
boards and **snapped off for production** — the production board keeps
just R26 (a 0 Ω in place of the J5 shunt, already counted in the 26
resistors above) plus the on-board Tag-Connect pads. Dev-rail headers add
~£1.50 in parts to a dev board but £0 to the production BOM.

---

## PAI ground anchor BOM (A3-A6 — 4× per pitch)

The **same board** as the stump anchor, with the USB-C receptacle
swapped for a magnetic charging connector (to maintain IP67) and a
sealed housing instead of a stump cap:

| Component | Part number | £ each | Notes |
|---|---|---:|---|
| Stump anchor board, less USB-C receptacle | per above | 30.80 | £31.20 base − £0.40 USB-C receptacle |
| Magnetic charging connector | Rosenberger MagSafe-style 2-pin | 3.00 | Replaces USB-C to maintain IP67 |
| IP67 sealed cylinder enclosure | Custom CNC ali, ~50 mm diameter | 5.00 | Or potted ABS at higher volume |
| Anti-corrosion gasket | Generic EPDM O-ring | 0.20 | Threaded enclosure seal |
| **PAI anchor subtotal** | | **39.00** | Includes the IP67 housing |

Sits flush with the ground, threaded into a buried mounting cup. Magnetic
charging via a separate dock for off-season. The PCB is a one-component
fork of the stump anchor (connector footprint only) — same board family,
same Gerbers minus the USB-C cluster.

---

## Ball tag BOM (per ball)

| Component | Part number | £ each | Notes |
|---|---|---:|---|
| UWB+BLE+MCU module | Qorvo DWM3001C | 18.00 | Same as anchors. Integrated accel is low-g (±16g) — fine for ball motion/release detection but NOT impact magnitude, hence the separate ADXL372 below. |
| Impact accelerometer | Analog Devices ADXL372 | 4.00 | ±200g, for impact event timing (the DWM3001C's integrated accel saturates too low for cricket impacts) |
| LiPo cell | 200 mAh prismatic, 25×15×4 mm | 3.50 | Custom-spec, impact-survival rated |
| LiPo protection IC | DW01A + 8205A | 0.30 | Same as anchors |
| Charge IC | TI BQ24074 lite | 1.20 | Smaller version, lower max charge |
| LDO 3.0V | TLV75530 | 0.40 | (32 kHz crystal is on the DWM3001C module) |
| Custom flex-PCB | Custom 4-layer flex, ~30×40 mm | 5.00 | To fit curved ball interior |
| Magnetic charging contacts | Custom 2-pin springloaded | 2.00 | Embedded in ball seam line |
| Misc passives | | 1.00 | |
| Cricket ball outer shell | Phase 4a 3D-print or moulded | 15.00 | + impact-survival validation |
| Adhesive + assembly | | 2.40 | |
| **Subtotal per ball** | | **53.20** | Includes shell + assembly |

---

## Enclosure / mechanical (per stump anchor)

| Item | £ | Notes |
|---|---:|---|
| Stump-top cap (ABS injection moulded, custom) | 8.00 | At 1,000-piece volume; £20 at 100 |
| PCB mounting brackets / standoffs | 1.50 | M2 brass standoffs |
| Cell mounting clip | 0.50 | Holds 18650 securely |
| Gasket (IP54) | 0.30 | EPDM |
| Assembly + functional test labour | 8.00 | UK rates, ~10 min per unit |
| **Subtotal per stump anchor** | **18.30** | Excludes electronics |

PAI ground anchor enclosure is included in its line above (£8.20 for housing parts above).

---

## Tooling / setup (one-time)

| Item | £ | Notes |
|---|---:|---|
| Injection mould tooling (stump cap) | 5,000 | Amortise across volume |
| PCB stencil + paste mask | 200 | One-time |
| Test jigs / fixtures | 1,000 | Functional test stand |
| Certification (FCC / CE / UKCA) | 8,000 | Per product variant |
| **Total tooling** | **~£14,200** | Amortise: £142/pitch at 100 pitches |

---

## Optional / future additions

### v2: Spin tracking (per ball)

| Component | Part number | £ each |
|---|---|---:|
| 3-axis magnetometer | Bosch BMM350 | 4.50 |
| Additional ball-side flash | Adds spin data | 1.00 |
| **v2 ball delta** | | **+5.50** |

### v2: PDoA / AoA capability (per anchor)

| Component | Part number | £ each |
|---|---|---:|
| Second UWB antenna | Yageo CHIP UWB ant | 1.50 |
| Antenna bar (custom CNC ali, ~180 mm) | | 4.00 |
| Additional RF switching | | 1.00 |
| **v2 anchor delta** | | **+6.50** |

### v3+: Full-match offline buffer

Replace W25Q128 with W25Q01JV (128 MB / 1 Gb): **+£8**. Since the flash
is populated on every board, this would apply per-board unless the
larger part is fitted only on the board assigned the hub role.

---

## Suppliers

| Component family | Primary supplier | Backup | Lead time |
|---|---|---|---|
| Qorvo DWM3001C | Digi-Key | Mouser, Farnell | In stock (same module as DWM3001CDK dev kit) |
| Passives (caps, resistors) | LCSC | Mouser | 1-2 weeks |
| 18650 cells | Battery Supplies UK | Vapcell | 1-2 weeks |
| PCB fab | PCBWay (proto), JLCPCB (volume) | OSH Park | 1-3 weeks |
| Enclosures (low vol) | Sculpteo, Protolabs | local 3D print | 3-5 days |
| Enclosures (high vol) | Chinese injection moulders | UK options | 8-12 weeks tooling |
| Magnetic chargers | Rosenberger UK | RS Components | 2-4 weeks |

---

## Cost trajectory (target)

| Volume | Per-pitch electronics | Notes |
|---|---:|---|
| Prototype (1-10) | ~£500 | Dev kits + breadboarded parts |
| Low volume (100) | **~£300** | Current state — this BOM |
| Mid volume (1,000) | ~£180 | Custom modules, bulk parts |
| High volume (10,000+) | ~£100 | Direct chip purchase, large reels |

The DWM3001C module is the dominant cost driver (~65%). At high volume, custom integration of the DW3110 + nRF52833 bare die (no module overhead) could roughly halve unit cost.

---

## Change log

| Date | Change | Rationale |
|---|---|---|
| 2026-05-14 | Passives line: "~40 parts" → exact "47 parts (19C/26R/1 ferrite/1 TVS)" | Schematic capture complete (anchor-board §4.1-4.9 + dev rail), ERC clean. Count is now exact, not estimated. Cost held at £0.80 — within prior estimate noise. |
| 2026-05-14 | Added break-off dev-rail note (J2-J7 headers); confirmed £0 production cost | Dev-rail headers are on the V-scored break-off strip, snapped off for production. Only R26 (0 Ω shunt replacement) and the Tag-Connect pads remain. From schematic capture + footprint assignment. |
| 2026-05-14 | RGB LED: "0805 SMD" → "PLCC-4 3.2×2.8 mm"; flagged orderable-code check | Footprint assigned is the Würth PLCC-4 150141M173100 land pattern; the BOM's "0805" descriptor was wrong. Exact Würth orderable to be confirmed against the footprint. |
| 2026-05-14 | Footprints assigned to all parts; DWM3001C footprint from official Qorvo Altium library | Schematic now has valid footprints (stock KiCad libs + 3 project footprints); ERC 0/0. DWM3001C land pattern decoded from Qorvo's IntLib rather than hand-traced. TPD2E2U06 corrected to its real 6-pin SOT-563; TLV75530 confirmed as X2SON-4 (no thermal pad). |
| 2026-05-14 | Merged dumb + hub anchor into one "Stump anchor" line; flash + load switch now populated on every board | Single assembly BOM, any anchor hub-promotable by reflashing. Hub is firmware-only. +£1.20/board on the 7 non-hub boards is noise. See `hardware/anchor-board/README.md`. |
| 2026-05-14 | PCB 30×40 mm → ~25×145 mm, £2.00 → £3.50 | Tall-and-thin form factor to slide vertically inside the stump tube. From the anchor-board design. |
| 2026-05-14 | "Bulk caps ×4" + "Misc passives" → single "Passives (~40 parts)" line, £0.70 → £0.80 | Expanded to the itemised schematic-level list (incl. VBAT sense divider, USB shield RC) in the anchor-board doc. |
| 2026-05-14 | PAI anchor is now explicitly the same board as the stump anchor (connector swap), not "same electronics" | One unified board design across all 8 anchors. |
| 2026-05-14 | USB ESD: TPD4S014 → TPD2E2U06 (CC lines) + a VBUS TVS diode | TPD4S014 is a USB data-port protector — wrong fit for this sink-only, power-only port. From anchor-board schematic capture, README §4.2. |
| 2026-05-14 | Added BQ24074 ILIM + ITERM program resistors (R24/R25) to the passives list | The original README §4.3 charger network omitted both program pins. From schematic capture. |
| 2026-05-14 | Removed C17 (TPS22916 "CT" cap) from the passives list | The TPS22916 (4-pin WCSP) has no CT pin — slew rate is set by the part variant. From schematic capture, README §4.6. |
| 2026-05-13 | Initial BOM | First active version, captures architecture decisions through May 13, 2026 |
| 2026-05-13 | 32 kHz crystal added to all anchors | RTC accuracy for BLE timing + log timestamps |
| 2026-05-13 | Flash: W25Q256 → W25Q128 | Disconnect-cache model (phone is source of truth), 16 MB plenty |
| 2026-05-13 | Battery: 2× 18650 → 1× 18650 | Power budget showed 290 days runtime on 1×, full cricket season |
| 2026-05-13 | QPK3000 → QPK3000ATR13 | omlox variant for peer-to-hub data path |
| 2026-05-13 | Added LIS2DH12 accelerometer to all anchors | Stump-side ball-strike detection, motion-wake for deep sleep, knockover detection. The QPK3000 doesn't integrate one (unlike DWM3001C). |
| 2026-05-13 | Added TPS22916 flash load switch on hub | Gates W25Q128 power in deep sleep, saves ~1 µA. Worth £0.20 in a battery-life product. |
| 2026-05-13 | USB ESD: clarified TPD4S014 as TVS+ESD array | Critical for outdoor / human-handled product. |
| 2026-05-14 | QPK3000ATR13 → DWM3001C | Available now, dev kit = production module, integrates a 3-axis accel + the 32 kHz LFXO crystal, nRF52833 / nRF Connect SDK. ~£8/anchor cheaper. Removed standalone LIS2DH12 + 32 kHz crystal + load caps lines. omlox no longer pre-loaded — peer-to-hub data path is now a thin fixed-schedule TDMA layer on the 802.15.4z PHY. |

---

## Reference links

- [Qorvo DWM3001C product page](https://www.qorvo.com) (datasheet, ordering codes — same module as the DWM3001CDK dev kit)
- [Digi-Key Qorvo UWB modules](https://www.digikey.com/en/products/filter/rf-transceiver-modules)
- [Winbond W25Q128JV datasheet](https://www.winbond.com)
- [Abracon 32 kHz crystals](https://abracon.com)
- [Architecture document](architecture.md) — full system spec
- [Phase 1+2 test plan](phase1-2-test-plan.md) — hardware bring-up

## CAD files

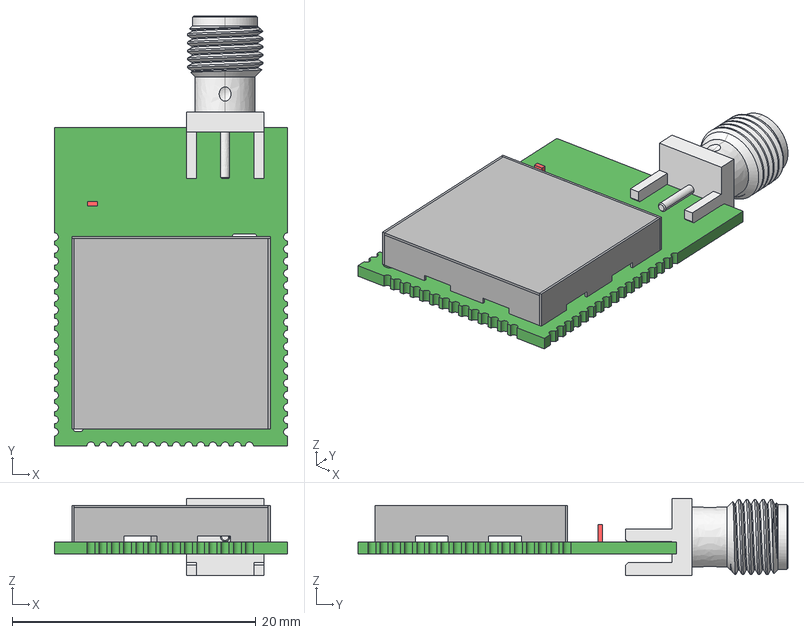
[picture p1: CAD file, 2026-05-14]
hardware/anchor-board/3d/DWM3001C.step
19.1 x 35.3 x 6.35 mm
Open_CASCADE_STEP_translator_6.8_5.1.1.1
DWM3001_shield_RGB8421504
DWM3001_shield_RGB8421505
DWM3001_shield_RGB8421506
DWM3001_shield_RGB8421507
DWM3001_shield_RGB8421508
_32322_3d_model_file
Extruded

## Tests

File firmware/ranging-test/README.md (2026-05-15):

# ranging-test — Phase 1.0 bring-up app

A freestanding Zephyr application that initialises the DW3110 inside
each DWM3001CDK and (eventually) runs DS-TWR ranging between two
boards. It is the first hardware-validation app — once it prints the
expected DW3110 device ID (`0xDECA0302`), the entire hardware path
(board overlay → SPI3 → CS/IRQ/RESET pins → driver → chip) is proven,
and the remaining work is application logic.

## Dependencies

This app depends on **`br101/zephyr-dw3000-decadriver`** — Bruno
Randolf's ISC-licensed Zephyr port of Qorvo's official DW3000 driver.
Clone it into the NCS workspace once:

```bash
git clone https://github.com/br101/zephyr-dw3000-decadriver.git \
  ~/ncs/v3.3.0/modules/lib/zephyr-dw3000-decadriver
```

The underlying Qorvo driver source (in
`dwt_uwb_driver/`) ships under Qorvo's proprietary licence
(`LicenseRef-QORVO-2`) — preserved on those files. Bruno's wrapper
and our application code remain Apache-2.0.

## Build

```bash
nrfutil toolchain-manager launch --ncs-version v3.3.0 \
  --chdir ~/ncs/v3.3.0 -- west build -p \
  -b decawave_dwm3001cdk/nrf52833 \
  $PWD/firmware/ranging-test -d /tmp/is_ranging_test \
  -- -DZEPHYR_EXTRA_MODULES=$HOME/ncs/v3.3.0/modules/lib/zephyr-dw3000-decadriver
```

## Flash

```bash
nrfutil toolchain-manager launch --ncs-version v3.3.0 \
  --chdir ~/ncs/v3.3.0 -- west flash --build-dir /tmp/is_ranging_test
```

Connect to the J-Link VCOM serial port at 115200 baud to see the boot
output.

## Layout

| File | Purpose |
|---|---|
| `CMakeLists.txt` | Zephyr app skeleton |
| `prj.conf` | Enables SPI, GPIO, the DW3000 driver, logging |
| `boards/decawave_dwm3001cdk_nrf52833.overlay` | Adds the DW3110 as a child of `&spi3`; pins IRQ to P1.2, RESET to P0.25, WAKEUP to P1.19 (per the DWM3001C internal wiring) |
| `src/main.c` | Bring-up smoke test — driver init, reset, device ID read |

## Status

- **Build:** passes, links cleanly against the driver and our overlay.
- **Runtime:** `dw3000_hw_init()` succeeds; `dw3000_hw_reset()`
  currently triggers an MPU instruction-access fault — under
  investigation. The driver is parsing the overlay correctly (pins
  log out with the right numbers); the fault is somewhere in the
  reset path.

This app will grow into the actual DS-TWR ranging test (initiator
on one board, responder on the other, ranges printed over UART) once
the bring-up smoke test passes.

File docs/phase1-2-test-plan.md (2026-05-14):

# Phase 1 + 2 Test Plan — Per-link σ + NLOS Characterisation

This is the first empirical validation block. It answers the two
foundation questions every other sim conclusion depends on:

1. **Phase 1:** Is the per-anchor ranging σ really ~30 mm outdoors?
2. **Phase 2:** Is the chip-level NLOS detection really ~85% TPR, and
   what does the real NLOS bias distribution look like?

All tests use the **Qorvo DWM3001CDK** (Digikey part `2312-DWM3001CDK-ND`,
~£26 inc-VAT each, currently 668 in stock UK).

---

## Equipment

| Item | Qty | Cost | Notes |
|---|---|---|---|
| DWM3001CDK | 3 | £78.69 | 2 active + 1 spare |
| USB-C cable | 3 | — | For power + data |
| Mini tripod or camera mount | 2 | ~£20 | Hold anchor + tag steady |
| Laser distance meter (e.g., Bosch GLM 50-23 G) | 1 | ~£60 | Ground truth to ±2 mm |
| Outdoor space, ~30 m clear sight line | — | — | Park or cricket club outfield |
| Laptop with USB | 1 | — | Data logging |
| **Initial spend** | | **~£160** | (£100 if rangefinder borrowed) |

Optional but useful:
- Volunteer for Phase 2 occlusion tests
- Bench scale to weigh things (if doing tag-in-shell early)
- Logitech webcam or phone on tripod for visual sync of occlusion events

---

## Phase 1.0 — Firmware Bring-Up (PREREQUISITE)

Before any data collection, the boards need firmware that:
- Performs DS-TWR between two boards
- Reads diagnostic registers after each exchange: `IP_DIAG_*`, `STS_DIAG_*`,
  `RX_POWER`, `FP_POWER`, the `RX_TIME` quality bits
- Logs everything over UART/USB serial as CSV
- Records each range with its diagnostic context

**Starting point:** Qorvo's `ex_06a_ss_twr_initiator` and `ex_06b_ss_twr_responder`
example pairs in the DW3000 SDK. Modify to:
1. Switch to DS-TWR (`ex_05a` / `ex_05b`) for clock-cancellation
2. Add diagnostic register reads after each exchange (see User Manual sec 4.7)
3. Print CSV to USB CDC

**Output format per ranging exchange:**

```
timestamp_ms, range_mm, rx_power_dbm, fp_power_dbm,
  fp_to_total_ratio, ip_diag_status, sts_quality_flag, anchor_id, tag_id
```

**Effort:** 1 weekend if comfortable with nRF Connect SDK; 2-3 weekends if
learning it from scratch. The Qorvo examples compile out-of-the-box,
the work is just adding the diagnostic readouts.

**Acceptance:** two boards in line-of-sight at 5 m report ranges ~5000 mm
with σ < 50 mm in a 1000-sample log, with all diagnostic fields populated.

---

## Phase 1.1 — Per-link σ vs Distance

**Question:** Does the chip deliver datasheet-rated 30 mm σ at the
distances we'll use in cricket geometry?

**Setup:**
- Anchor on tripod at 1 m height
- Tag on tripod at 1 m height
- Measure horizontal distance with laser rangefinder to ±5 mm
- Clean line of sight, no people walking by

**Procedure:**
1. Set distance to 1 m, log 1000 ranges (~30 sec at 30 Hz update)
2. Repeat at 5 m, 10 m, 15 m, 20 m, 25 m
3. Repeat the whole sweep 3× over a day (morning / midday / evening) to
   catch temperature effects
4. At each distance, log the diagnostic registers too (we'll use these
   in Phase 2)

**Analysis:**
- σ vs distance: should be roughly flat ~30 mm, perhaps creeping up at 20+ m
- Mean bias vs distance: should be roughly constant (antenna delay
  calibrated out)
- Outlier rate: % of ranges > 3σ from mean

**Pass criteria:**
- σ ≤ 35 mm across all distances tested
- Mean bias < ±20 mm at any distance
- < 1% outliers (anything more suggests preamble detection issues)

**Failure modes:**
- σ > 50 mm everywhere → calibration problem in firmware, dig in
- σ ramps up sharply at 15-20 m → link budget marginal, check antenna or power settings
- Mean bias drifts > 100 mm between distances → antenna delay needs proper calibration
- Different from morning to evening → temperature effect, expected but
  document magnitude

**Estimated time:** 1 full afternoon (4 hours) including setup.

---

## Phase 1.2 — Antenna Delay Calibration

**Question:** What's the systematic per-board antenna delay, and once
calibrated, what σ do we get?

This is genuinely production-relevant. The chip ships uncalibrated;
deployment needs each anchor calibrated individually.

**Setup:**
- Same as 1.1 but with 3 boards in a triangle, all known distances
- Each pair gets ranged

**Procedure:**
1. Place 3 boards at known positions forming a triangle (e.g., 5, 7, 9 m sides)
2. Log 500 ranges per pair (3 pairs)
3. Compute systematic per-pair bias: `bias_AB = mean(measured) - true`
4. Solve the 3-equation system to get per-board antenna delays
5. Apply calibration, re-measure, confirm bias < 10 mm

**Pass criteria:** Post-calibration mean bias on each pair < 10 mm.

**Estimated time:** 2 hours.

---

## Phase 2.1 — NLOS Bias Distribution (human in line)

**Question:** When a human stands in the anchor-tag line, what's the
distribution of (a) drop rate, (b) range bias, (c) chip diagnostic
signature?

**Setup:**
- Anchor at one end, tag at other end, 10 m apart, both at 1.5 m height
  (representative ball-flight zone)
- Volunteer positioned to stand in or near the line

**Procedure:**

For each of these positions, log 500 ranges + full diagnostic registers:

1. **Clean LOS** — volunteer standing 5 m to the side of the line
2. **Direct torso block** — volunteer standing in the line, 5 m from anchor,
   facing perpendicular (max torso block)
3. **Partial occlusion** — volunteer offset 0.5 m from the line
4. **Edge occlusion** — volunteer offset 1.0 m from the line
5. **No occlusion (cross-check)** — volunteer offset 2.0 m from the line
6. **Walking through** — volunteer walks across the line at ~1 m/s (5-10
   passes, total ~500 ranges)

Optional / nice-to-have:
- Hand-label each sample with a binary "blocked / clear" tag using
  the recording or timestamps
- Repeat with different body orientations (facing along the line, vs
  perpendicular) to test orientation sensitivity

**Analysis:**

For each position:
- Mean range bias (measured − true) — should be 0 for LOS, positive for NLOS
- σ of measurements
- Drop rate (fraction returning no range / invalid status)
- Histogram of `fp_power - rx_power` ratio (this is the NLOS metric)

Plot:
- `fp_power - rx_power` vs LOS/NLOS label → shows separability
- Compute classifier ROC curve, find threshold that gives ~85% TPR and
  measure actual FPR at that threshold

**Pass criteria:**
- Direct torso block produces detectable bias (mean shift > 20 mm vs LOS)
  OR clear drop in success rate
- The `fp/rx_power` ratio separates LOS from NLOS classes — i.e., the
  ROC curve sits above the diagonal
- At a threshold giving 80% TPR, FPR < 10%

**Failure modes:**
- No detectable bias under torso block → reflection/diffraction model
  was wrong; need to rethink the NLOS hypothesis
- `fp/rx_power` doesn't separate classes → can't build a usable NLOS
  classifier from datasheet metrics, need raw CIR ML approach
- Bias is in the wrong direction (negative) → unexpected, would suggest
  early-path detector is misbehaving

**Estimated time:** 1 full evening (~2-3 hours including setup and
volunteer coordination).

---

## Phase 2.2 — Statistical NLOS Characterisation

**Question:** What does the realistic distribution of NLOS biases look
like across many occluder configurations?

**Setup:**
- Same as 2.1
- Multiple volunteers, ~5-10 people of different builds if possible

**Procedure:**
1. Volunteer walks naturally across the line of sight repeatedly while
   ranges log continuously
2. Have 2-3 volunteers walking in random patterns simultaneously
3. Log 30 minutes of data with people moving around naturally
4. Hand-label periodically using camera footage or live notes

**Analysis:**
- Aggregate distribution of biases from all NLOS-labelled samples
- Compare to the assumption from sim 05: uniform(50 mm, 200 mm) + N(0, 100 mm)
- Tail behaviour — what's the p95, p99 bias?

**Pass criteria (purely informational, no fail):**
- Distribution roughly uniform in 50-200 mm range, OR
- Distribution distinctly different (heavy tail, bimodal, etc.) → update
  sim 05 assumptions

**Estimated time:** 1 evening + a couple of evenings of analysis.

---

## Phase 2.3 — Spinning Tag Antenna Pattern (Phase 4a precursor)

**Question:** Does the tag's antenna gain pattern, when the tag rotates,
produce systematic drops in ranging from any one anchor direction?

This is technically Phase 4a but is cheap enough to include here while the
kit is set up.

**Setup:**
- Tag mounted on a cheap brushless motor (RC car / drone motor + ESC), free-spinning
- Spin rate adjustable from 0 to 1500 RPM (= 25 rev/s, peak cricket spin)
- Anchor 10 m away

**Procedure:**
1. Static baseline: 500 ranges with tag stationary
2. Slow spin: 1 Hz, 500 ranges
3. Medium spin: 10 Hz, 500 ranges
4. Cricket-fast spin: 25 Hz, 500 ranges
5. Repeat with anchor at different angles relative to tag rotation axis
   (perpendicular, parallel, 45°)

**Analysis:**
- Look for periodic structure in range time series at the spin period
- Compute drop rate per spin condition
- Check σ vs spin rate

**Pass criteria:**
- No systematic dropouts > 50 ms at any spin rate
- σ at 25 rev/s ≤ 1.5× static σ

**Failure modes:**
- Periodic drops at the spin period → antenna has a deep null; needs
  diversity antennas or different antenna design before going to Phase 4
- σ inflates dramatically with spin → Doppler / phase effects we hadn't
  modelled

**Estimated time:** 1 evening + ~£20 for motor/ESC.

---

## Data Logging Format

All tests log to CSV. Columns:

```
test_id              # which test this row belongs to
timestamp_ms         # since recording started
distance_true_mm     # ground truth (from laser meter)
range_meas_mm        # what the chip reported
rx_power_dbm
fp_power_dbm
ratio                # fp_power - rx_power (the NLOS metric)
ip_diag_status       # bitfield from IP_DIAG status word
sts_quality_flag     # STS dual-estimate flag (high = error)
sts_diag_status      # bitfield from STS_DIAG status word
label                # MANUAL: "los", "nlos-torso", "nlos-walking", etc
anchor_id            # which board was anchor
tag_id               # which board was tag
notes                # free text
```

Plus a `metadata.json` per session with weather, temperature, location,
orientation, volunteer count etc.

---

## Acceptance Summary — Phase 1+2 Outcome

After all tests complete, you can answer:

| Question | Source test | If pass → | If fail → |
|---|---|---|---|
| σ matches sim assumption (30 mm)? | 1.1 | Continue to Phase 3 | Rescale sim numbers, reconsider |
| Antenna delay calibrable to < 10 mm? | 1.2 | Production tooling is feasible | Need per-anchor cal procedure design |
| NLOS bias detectable in chip diagnostics? | 2.1 | Build classifier on these features | Need CIR-based ML classifier (more work) |
| NLOS bias distribution matches sim 05 assumption? | 2.2 | sim 05b numbers are valid | Update sim and re-estimate operational target |
| Spinning antenna survives 25 rev/s without dropouts? | 2.3 | In-ball architecture is feasible | Antenna redesign before Phase 4 |

If all five questions pass → **Phase 3 (full cricket geometry) is the next step**, and the system has cleared the major risk gates the simulations couldn't.

If 2.3 fails specifically → reconsider in-ball architecture (might need diversity antennas, or accept that anchors at certain angles will always be flaky).

---

## Total Phase 1+2 Effort Estimate

| Element | Time | Cost |
|---|---|---|
| Firmware bring-up (Phase 1.0) | 1-3 weekends | — |
| Phase 1.1 — σ vs distance | 1 afternoon | £60 if buying rangefinder |
| Phase 1.2 — antenna calibration | 2 hours | — |
| Phase 2.1 — NLOS bias single subject | 1 evening | — |
| Phase 2.2 — NLOS bias statistical | 1 evening + analysis | — |
| Phase 2.3 — spinning tag | 1 evening | ~£20 motor |
| **Total** | **3-5 weekends spread over 4-8 weeks** | **~£260** (incl. 3 boards) |

Outcome: you know whether the operational headline (~65-90 mm fit RMS
under realistic conditions) is real or a sim artefact, and whether
the chip's diagnostic registers genuinely enable NLOS detection at
the rates we assumed. This is the data that backs the patent filing.

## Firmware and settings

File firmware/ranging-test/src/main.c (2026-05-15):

/*
 * Copyright (c) 2026 Infinity Stumps
 * SPDX-License-Identifier: Apache-2.0
 *
 * Phase 1.0 firmware-bringup smoke test.
 *
 * Initialise the DW3110 over SPI via br101's Zephyr DW3000 driver,
 * walk it through the canonical Qorvo init sequence
 * (hw reset -> dwt_probe -> wait for IDLE_RC -> dwt_initialise),
 * then read the chip's 32-bit device ID. A correct read proves the
 * whole hardware path works end to end: board overlay, SPI3,
 * CS/IRQ/RESET pins, the driver's platform layer, the Qorvo API.
 *
 * Expected device ID for the DW3110 on the DWM3001C: 0xDECA0302.
 */

#include <zephyr/kernel.h>
#include <zephyr/sys/printk.h>

#include <dw3000_hw.h>
#include <deca_device_api.h>
#include <deca_probe_interface.h>

int main(void)
{
	printk("\n=== Infinity Stumps ranging-test ===\n");
	printk("Board: %s\n", CONFIG_BOARD);

	printk("dw3000_hw_init... ");
	int ret = dw3000_hw_init();
	if (ret < 0) {
		printk("FAILED (%d)\n", ret);
		return ret;
	}
	printk("OK\n");

	printk("dw3000_hw_reset...\n");
	dw3000_hw_reset();
	k_msleep(2);

	printk("dwt_probe...\n");
	int32_t rc = dwt_probe((struct dwt_probe_s *)&dw3000_probe_interf);
	printk("  -> %d\n", rc);

	printk("waiting for IDLE_RC...\n");
	int timeout_ms = 200;
	while (!dwt_checkidlerc() && timeout_ms-- > 0) {
		k_msleep(1);
	}
	if (timeout_ms <= 0) {
		printk("  TIMEOUT — chip didn't reach IDLE_RC state\n");
	} else {
		printk("  IDLE_RC reached\n");

		printk("dwt_initialise... ");
		if (dwt_initialise(DWT_DW_INIT) == DWT_ERROR) {
			printk("FAILED\n");
		} else {
			printk("OK\n");
		}
	}

	uint32_t devid = dwt_readdevid();
	printk("\nDW3110 device ID: 0x%08x  (expected 0xDECA0302)\n", devid);

	if (devid == 0xDECA0302) {
		printk("PASS — chip is talking to us.\n");
	} else {
		printk("FAIL — unexpected ID, check wiring / overlay.\n");
	}

	while (1) {
		k_sleep(K_SECONDS(10));
	}

	return 0;
}

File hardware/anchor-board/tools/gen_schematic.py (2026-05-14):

#!/usr/bin/env python3
"""Generate anchor_board.kicad_sch — the anchor-board schematic netlist.

This script authored the schematic by placing components and connecting
them with same-named local labels / global power ports (no hand-tracked
UUIDs). It captures the full design: §4.1-4.9 from the anchor-board
README plus the §7 break-off dev rail. ERC-clean (0/0).

  Run from anywhere:  python3 hardware/anchor-board/tools/gen_schematic.py

IMPORTANT — this REGENERATES the whole sheet. Re-running it clobbers any
manual layout/tidying done in KiCad. Once the schematic has been
hand-tidied, treat `anchor_board.kicad_sch` as the source of truth and
retire this script — or, for a connectivity change, edit here and
re-run, then re-tidy. The netlist (which pins connect to which net) is
the part worth keeping here; the x/y placement is just a starting point.

Layout notes:
- Components sit on a 1.27 mm grid (on_grid() asserts this).
- Each label is pulled off its pin onto a short stub wire and oriented
  to read *away* from the component body, so text doesn't pile up on the
  component edge or overlap neighbours. Densely-packed pin columns get
  alternating stub lengths so adjacent labels stagger.
- Power ports and no-connects stay on the pin (ports are compact
  graphics; NC flags must sit on the pin to mark it).

KiCad symbol library path can be overridden with $KICAD_SYMBOL_DIR.
"""
import os
import re
import uuid
from collections import defaultdict

_HERE = os.path.dirname(os.path.abspath(__file__))
_BOARD = os.path.normpath(os.path.join(_HERE, ".."))

KSYM = os.environ.get(
    "KICAD_SYMBOL_DIR",
    "/Applications/KiCad/KiCad.app/Contents/SharedSupport/symbols")
PROJ_SYM = os.path.join(_BOARD, "anchor_board.kicad_sym")
OUT = os.path.join(_BOARD, "anchor_board.kicad_sch")
ROOT = "ccc23363-f05f-472d-883e-00c200b7d03a"
PROJECT = "anchor_board"
GRID = 1.27
STUB = 2.54  # base label stub length; dense columns alternate STUB / 2*STUB


def u():
    return str(uuid.uuid4())


def on_grid(x, y, what):
    for v in (x, y):
        if abs(round(v / GRID) * GRID - v) > 1e-6:
            raise AssertionError("OFF-GRID %s: (%s, %s)" % (what, x, y))


def extract_symbol(text, name):
    i = text.index('(symbol "%s"' % name)
    d = 0
    for k in range(i, len(text)):
        if text[k] == '(':
            d += 1
        elif text[k] == ')':
            d -= 1
            if d == 0:
                return text[i:k + 1]
    raise ValueError(name)


def embed(block, name, lib_id):
    block = block.replace('(symbol "%s"' % name, '(symbol "%s"' % lib_id, 1)
    out = []
    for n, line in enumerate(block.split("\n")):
        if line.lstrip().startswith("#"):
            continue
        out.append(("\t\t" if n == 0 else "\t") + line)
    return "\n".join(out)


def parse_pins(block):
    pins = {}
    for m in re.finditer(
        r'\(pin\s+\S+\s+\S+\s*\(at ([-\d.]+) ([-\d.]+) [-\d.]+\)\s*'
        r'\(length [\d.]+\)\s*\(name "[^"]*".*?\(number "([^"]+)"', block, re.S):
        x, y, num = m.groups()
        pins[num] = (float(x), float(y))
    return pins


dev = open(KSYM + "/Device.kicad_sym").read()
pwr = open(KSYM + "/power.kicad_sym").read()
sw = open(KSYM + "/Switch.kicad_sym").read()
conn = open(KSYM + "/Connector.kicad_sym").read()
cgen = open(KSYM + "/Connector_Generic.kicad_sym").read()
prj = open(PROJ_SYM).read()

raw = {
    "Device:C": extract_symbol(dev, "C"),
    "Device:R": extract_symbol(dev, "R"),
    "Device:L": extract_symbol(dev, "L"),
    "Device:D_TVS": extract_symbol(dev, "D_TVS"),
    "Device:Battery_Cell": extract_symbol(dev, "Battery_Cell"),
    "Device:LED_ARGB": extract_symbol(dev, "LED_ARGB"),
    "Switch:SW_Push": extract_symbol(sw, "SW_Push"),
    "Connector:TestPoint": extract_symbol(conn, "TestPoint"),
    "Connector_Generic:Conn_01x02": extract_symbol(cgen, "Conn_01x02"),
    "Connector_Generic:Conn_01x03": extract_symbol(cgen, "Conn_01x03"),
    "Connector_Generic:Conn_01x06": extract_symbol(cgen, "Conn_01x06"),
    "Connector_Generic:Conn_02x03_Odd_Even": extract_symbol(cgen, "Conn_02x03_Odd_Even"),
    "Connector_Generic:Conn_02x05_Odd_Even": extract_symbol(cgen, "Conn_02x05_Odd_Even"),
    "power:GND": extract_symbol(pwr, "GND"),
    "power:PWR_FLAG": extract_symbol(pwr, "PWR_FLAG"),
    "infinity-stumps:DWM3001C": extract_symbol(prj, "DWM3001C"),
    "infinity-stumps:3V0": extract_symbol(prj, "3V0"),
    "infinity-stumps:VSYS": extract_symbol(prj, "VSYS"),
    "infinity-stumps:VBAT": extract_symbol(prj, "VBAT"),
    "infinity-stumps:VBUS": extract_symbol(prj, "VBUS"),
    "infinity-stumps:TLV75530": extract_symbol(prj, "TLV75530"),
    "infinity-stumps:DW01A": extract_symbol(prj, "DW01A"),
    "infinity-stumps:FS8205A": extract_symbol(prj, "FS8205A"),
    "infinity-stumps:BQ24074": extract_symbol(prj, "BQ24074"),
    "infinity-stumps:TPD2E2U06": extract_symbol(prj, "TPD2E2U06"),
    "infinity-stumps:USB4105-GF-A": extract_symbol(prj, "USB4105-GF-A"),
    "infinity-stumps:W25Q128JV": extract_symbol(prj, "W25Q128JV"),
    "infinity-stumps:TPS22916C": extract_symbol(prj, "TPS22916C"),
}
bare = {k: k.split(":")[1] for k in raw}
PINS = {lib: parse_pins(blk) for lib, blk in raw.items()}
lib_syms = [embed(raw[lib], bare[lib], lib) for lib in raw]
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

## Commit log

2026-05-14 Initial commit: Cricket UWB ball-tracking + LBW prediction system
    Phase 0 simulation work for a low-cost UWB cricket ball tracker —
    "DRS for the rest of us". Includes the physics-EKF + RTS smoother
    analytics pipeline, LBW verdict module, simulation harnesses, and
    full design documentation (architecture, BOM, prior-art strategy).
    Hardware platform: Qorvo DWM3001C. Open source under Apache-2.0
    (software), CERN-OHL-S-2.0 (hardware), CC-BY-4.0 (docs).
2026-05-14 Switch to DWM3001C, tidy up the codebase, rename to Infinity Stumps
    Hardware platform:
    - Switch from Qorvo QPK3000 to DWM3001C across all docs (available
    now, dev kit = production module, integrates accel + 32 kHz crystal)
    Developer tooling:
    - Add ruff (lint + format), mypy, pre-commit, .editorconfig
    - Add Makefile (install/test/lint/typecheck/check/sims/clean)
    - Add GitHub Actions CI across Python 3.10-3.12
    - Flesh out pyproject.toml: metadata, URLs, classifiers, dev extras
    Tests:
    - Restructure the single test_core.py into conftest.py + six
    per-module suites (56 tests), covering the previously-untested
    EKF and LBW modules
    Package hygiene:
    - Fix __init__.py exports (EKF, LBW, gdop_m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
2026-05-14 Restructure as a monorepo: simulation/ + firmware/ hardware/ app/
    The repo now has one directory per discipline so it can hold the
    firmware, PCB/mechanical design, and mobile app alongside the Python
    work — rather than looking like a Python project with extras bolted on.
    - Move the Python project into simulation/ (src, sims, tests, outputs,
    pyproject.toml, Makefile) — git tracks these as renames
    - Add skeleton directories with READMEs:
    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
2026-05-14 Add anchor-board PCB design doc, reconcile BOM/architecture
    Specify the in-stump anchor PCB as a single unified board for all 8
    anchor positions: a tall-and-thin (~25x145 mm) DWM3001C carrier that
    slides inside the stump, designed as a dev board that converts to the
    production board by snapping off a V-scored dev rail. Includes the full
    passive list, pin allocation, layout rules, and conversion checklist.
    Decisions baked in: flash + load switch populated on every board (hub is
    firmware-only, any board hub-promotable), PAI anchor is a one-component
    connector fork of the same board, soft-wake power button, on-board
    antenna keepout.
    Reconcile docs/bom.md, docs/architecture.md, docs/spec-v0.2.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
2026-05-14 hw(anchor-board): start KiCad schematic — scaffold + §4.1 module block
    - KiCad 10 project: .kicad_pro/.kicad_sch/.kicad_sym, sym/fp-lib-tables,
    empty anchor_board.pretty/ for the custom footprints
    - Project symbol lib: custom DWM3001C module symbol (castellation pin
    numbers are sequential placeholders — reconcile vs the Qorvo datasheet
    before layout) + VBUS/VSYS/VBAT/3V0 power-rail symbols
    - Title block (CERN-OHL-S v2), 5 power rails defined
    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
    [anchor_board.kicad_sch]
2026-05-14 hw(anchor-board): capture §4.5 TLV75530 LDO; record MCU decision
    - §4.5: U6 TLV75530 + C12/C13 1uF, C14 10uF, FB1 ferrite. The LDO OUT
    now drives the 3V0 rail, so the §4.1 3V0 PWR_FLAG placeholder is gone.
    - New TLV75530 symbol (DQN / X2SON-4 pinout per the TLV755P datasheet).
    - docs/mcu-tradeoff.md: decision to stay on the DWM3001C (not switch to
    DWM3000 + ESP32-C6), and solve developer onboarding by distributing
    pre-bootloadered boards. Includes the ESP32-C6 power model
    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
    [anchor_board.kicad_sch]
2026-05-14 hw(anchor-board): capture §4.4 cell protection; add IC symbols; A3 sheet
    - §4.4: BT1 18650 + U4 DW01A + U5 FS8205A + R13/C11/R14. DW01A+8205A
    back-to-back FET protection: cell+ -> VBAT, cell- -> BMINUS, the FET
    pair sits between BMINUS and system GND, DW_VCC fed via R13, current
    sense via R14, OD/OC gate drives, TD test pin no-connected.
    - 5 new project symbols authored from docs/datasheets/: BQ24074, DW01A,
    FS8205A, USB4105-GF-A, TPD2E2U06. DW01A CS is a passive sense pin.
    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
    [anchor_board.kicad_sch]
2026-05-14 hw(anchor-board): capture §4.3 BQ24074 charger
    - §4.3: U3 BQ24074 + C8/C9/C10 IN/OUT/BAT caps, R5 909R ISET, R6 TMR,
    R7/R8 10k TS divider, R9/R10 10k CHG/PGOOD pull-ups, R11/R12 0R EN
    straps, plus R24/R25 for the ILIM/ITERM program pins (README §4.3 gaps).
    - BQ24074 symbol: program / strap / sense pins set to passive; one of
    the dual OUT pins is passive so the shared node doesn't trip ERC.
    - Power path: charger OUT now drives VSYS (replacing §4.5's placeholder
    flag); BAT -> VBAT; CHG/PGOOD reach U1, clearing 4 ERC errors.
    ERC: 29 violations (was 32) - 25 are U1's not-yet-captured
    §4.2/4.6/4.7/4.8 pins, 4 are footprint-not-found warnings.
    [anchor_board.kicad_sch]
2026-05-14 hw(anchor-board): capture §4.2 USB-C input + ESD; swap ESD part
    - §4.2: J1 USB4105-GF-A + R2/R3 5.1k CC pull-downs, C5 10uF / C6 100nF
    VBUS caps, U2 TPD2E2U06 (CC-line ESD), D2 VBUS TVS, R4 1M + C7 4.7nF
    shield RC. VBUS now connector-driven; data/SBU lines no-connected
    (power-only port).
    - Part swap: TPD4S014 -> TPD2E2U06 + dedicated VBUS TVS. The TPD4S014
    is a USB data-port protector, wrong fit for a sink-only power port.
    README §4.2 + bom.md updated to match (+ changelog).
    - README §4.3: R24/R25 added for the BQ24074 ILIM/ITERM program pins.
    - docs/mcu-tradeoff.md: note JLCPCB's PCBA firmware-flashing service —
    fab can do the one-time bootloader flash, given on-board SWD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
    [anchor_board.kicad_sch]
2026-05-14 hw(anchor-board): capture §4.6 SPI flash + load switch
    - §4.6: U7 W25Q128 (16 MB SPI flash) + U8 TPS22916C load switch + C15
    100nF, C16 1uF, R15/R16/R17 10k pull-ups. TPS gates 3V0 -> 3V0_FLASH
    (switched flash rail); SPI bus + FLASH_EN connect to U1, clearing 6
    ERC errors.
    - 2 new project symbols: W25Q128JV (SOIC-8), TPS22916C (4-pin WCSP).
    - Spec correction: dropped C17 — the TPS22916 has no CT pin (slew rate
    is set by the part variant). README §4.6 + bom.md updated; C16 also
    corrected 0402 -> 0603 for consistency with the other 1uF caps.
    - docs/datasheets/: added W25Q128JV + TPS22916 datasheets.
    ERC: 26 violations (was 31) - 19 are U1's not-yet-captured §4.7/4.8 /
    dev-rail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
    [anchor_board.kicad_sch]
2026-05-14 Capture §4.7 RGB LED + power button on anchor-board schematic
    Adds D1 (common-anode RGB LED) with R18/R19/R20 cathode current-limit
    resistors to U1 LED_R/G/B pins, and SW1 power button with R21 pull-up
    and C18 debounce cap on the BTN net. U1 EN1/EN2 marked no-connect.
    ERC 26 -> 21 (remaining errors are U1 pins captured in §4.8/§4.9).
    [anchor_board.kicad_sch]
2026-05-14 Capture §4.8 VBAT voltage sense divider on anchor-board schematic
    Adds R22/R23 (1M+1M high-impedance divider) from VBAT with C19 100nF
    filter cap, tap driving U1 VBAT_SENSE (pin 9) for the hub's battery_pct
    BLE field. ERC 21 -> 19 (remaining errors are §4.9 dev-rail pins).
    [anchor_board.kicad_sch]
2026-05-14 Capture §4.9 rail test points + §7 break-off dev rail — schematic ERC-clean
    Completes the anchor-board schematic:
    - §4.9: TP1-TP6 (VBUS/VSYS/VBAT/3V0/GND x2) + C20 10uF 3V0 bulk cap
    - §7 dev rail: J2 2x5 SWD header, J8 Tag-Connect TC2030 pads, J3 UART
    header, J4 GPIO breakout, J5 3V0 current-shunt jumper (+ R26 0R
    production replacement), J6 LED-disable jumper, J7 reset/boot pads
    - LDO output split into 3V0_LDO -> (shunt jumper / 0R) -> 3V0 so the
    sleep-current meter sees true load current; LED anode on LED_VCC
    behind the disable jumper
    - DWM3001C SWDCLK/UART_RX pins -> passive (driven by external tooling)
    ERC: 0 errors, 10 warnings (all footprint-not-found placeholders for
    cu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
    [anchor_board.kicad_sch]
2026-05-14 Add official DWM3001C footprint + STEP model
    Footprint decoded from Qorvo's official Altium library (DWM3001C.IntLib):
    48 castellated SMD pads, 2.54 x 0.75 mm on 1.0 mm pitch, 3-sided
    (left 1-17, bottom 18-31 rotated 90, right 32-48), body 19.1 x 26.05 mm.
    Pad coords, outline, and antenna-end features taken verbatim from the
    vendor data rather than hand-traced. STEP model copied from the same
    library and referenced at 3d/DWM3001C.step.
    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
    [DWM3001C.step]
2026-05-14 Assign footprints to all anchor-board parts — schematic 0/0 ERC
    Footprint assignments:
    - DWM3001C: official Qorvo footprint (prior commit)
    - USB-C, 18650 holder, RGB LED, TC2030 pads, BQ24074 QFN-16,
    TPS22916 WLP-4: stock KiCad library footprints
    - TLV75530 X2SON-4 and Alps SKHHAL switch: new project footprints
    (land patterns approximate — flagged for verification before fab)
    Symbol fixes surfaced by footprint reconciliation:
    - TPD2E2U06: rebuilt as the real 6-pin SOT-563 (IO1=3, IO2=5, GND=4,
    pins 1/2/6 NC) — was a 3-pin stub
    - TLV75530: dropped the spurious thermal-pad pin 5 — DQN is X2SON-4,
    no thermal pad
    - USB4105: shield pin renamed S1 -> SH to match the footprint pad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
    [anchor_board.kicad_sch]
2026-05-14 Reconcile BOM against completed anchor-board schematic + footprints
    - Passives line: estimated "~40" → exact 47 (19 caps, 26 resistors,
    1 ferrite, 1 TVS) from completed schematic capture; cost held at £0.80
    - Added break-off dev-rail note: J2-J7 headers are snapped off for
    production, £0 production cost (only R26 0Ω + Tag-Connect pads remain)
    - RGB LED package corrected "0805" → PLCC-4 3.2×2.8mm to match the
    assigned Würth footprint; flagged the orderable code for confirmation
    - Changelog entries for footprint assignment + the DWM3001C footprint
    decoded from Qorvo's official Altium library
2026-05-14 Move §4.9 + dev-rail blocks inside the A3 sheet boundary
    The test points and break-off dev-rail connectors were placed at
    y=287-315, off the bottom edge of the A3 sheet. Relocated both blocks
    into the open area on the right side (x 305-375, y 145-245). All 72
    components now sit within the sheet; ERC still 0/0.
    [anchor_board.kicad_sch]
2026-05-14 Add schematic generator to repo + stub/orient labels for readability
    Moves the schematic generator out of /tmp into
    hardware/anchor-board/tools/gen_schematic.py so the netlist build is
    tracked. Paths are now relative to the script; the KiCad symbol dir is
    overridable via $KICAD_SYMBOL_DIR.
    Readability pass — every label and power port is now pulled off its pin
    onto a short stub wire and oriented to read *away* from the component
    body, instead of piling up on the component edge:
    - labels justified by pin direction so text never runs into the body
    - adjacent items in a pin column get alternating stub lengths to stagger
    - collision avoidance: a stub that would touch another pin or stub is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
    [anchor_board.kicad_sch]
2026-05-14 Group schematic into framed functional sections
    Each block (§4.1-4.9 + §7 dev rail) is now translated as a unit into
    its own region of the sheet and wrapped in a dashed frame with a
    heading, instead of components being scattered across the page.
    - SECTION_REFS maps every ref to its block; SECTION_TARGET gives each
    block a placement on the grid, roughly following power flow (USB-C
    top-left, rails across the top, module centre, peripherals down the
    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
    [anchor_board.kicad_sch]
2026-05-14 Reconcile DWM3001C symbol + netlist against the real castellation map
    The DWM3001C symbol was a 25-pin placeholder with sequential pin
    numbers that didn't match the module. Rebuilt it as the real 48-pin
    part:
    - new tools/gen_dwm3001c_symbol.py generates the symbol — all 48
    castellations numbered per the datasheet (Rev F §3), used pins named
    by board function, unused pins keep their datasheet GPIO name and are
    typed no_connect (those pads float by design)
    - function->GPIO assignment finalised: VBAT_SENSE on P0.31/AIN7 (ADC-
    capable), SWD/RESET on the dedicated pins, on-module accel I2C
    (P0.24/P1.04) and NFC pins (P0.09/P0.10) left NC
    - gen_schematic.py: §4.1 reworked from hand-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
    [anchor_board.kicad_sch]
2026-05-15 firmware: scaffold ranging-test bring-up app for the DWM3001CDK
    Adds firmware/ranging-test/, a freestanding Zephyr application that
    will grow into the Phase 1.0 DS-TWR ranging test. Currently a
    minimal smoke test that initialises the DW3110 over SPI and prints
    its device ID.
    - prj.conf enables SPI, GPIO, and br101's CONFIG_DW3000 driver.
    - boards/decawave_dwm3001cdk_nrf52833.overlay adds the DW3110 as a
    child of &spi3, with IRQ on P1.2, RESET on P0.25, WAKEUP on P1.19
    (from Qorvo's reference custom_board.h pin map).
    - src/main.c initialises the driver and reads the chip's device ID;
    expected to print 0xDECA0302 once the bring-up bug is resolved.
    Depends on br101/zephyr-dw3000-decadri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
    [main.c]
2026-05-15 ranging-test: add dwt_probe + IDLE_RC wait + dwt_initialise
    The previous main.c jumped from dw3000_hw_reset() straight to
    dwt_readdevid(), which dereferenced a null chip handle and faulted
    with an MPU instruction-access violation.
    Correct Qorvo init sequence:
    dw3000_hw_init -> Zephyr-side SPI / GPIO setup
    dw3000_hw_reset -> toggle the chip's RESET line
    dwt_probe -> register the driver and create the chip handle
    dwt_checkidlerc() -> wait until the chip is in IDLE_RC state
    dwt_initialise -> configure the chip itself
    dwt_readdevid() -> now safe to call
    Verified: device ID reads back as 0xDECA0302 on a DWM3001CDK rev C2.
    [main.c]
